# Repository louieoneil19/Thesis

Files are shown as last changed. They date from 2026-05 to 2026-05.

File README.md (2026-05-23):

# Solar-Powered Buck-Boost Converter — Thesis Project

An STM32-based MPPT buck-boost converter for solar-powered soil moisture monitoring and pump control.

## Overview

This project presents the design and implementation of a solar-powered irrigation system optimised for off-grid rural use. The system integrates a photovoltaic panel, a non-inverting DC–DC buck-boost converter, a backup battery, a water pump, and a microcontroller-based control unit on a custom four-layer printed circuit board. A perturb-and-observe maximum power point tracking (MPPT) algorithm is implemented to maximise energy extraction from the solar panel across varying irradiance and temperature conditions. A capacitive soil moisture sensor drives a separate pump-control loop, varying pump speed in discrete stages based on measured soil dryness. The converter was validated in MATLAB Simulink and characterised experimentally through duty-cycle sweeps, with the measured input–output relationships closely matching theoretical predictions. The completed system demonstrates autonomous solar energy harvesting and adaptive water delivery, providing a viable platform for off-grid agricultural applications in resource-limited regions.

## Repository Structure
```
.
├── firmware/          STM32CubeIDE project (STM32F446RE)
│   ├── Core/          Application source code (main.c, peripherals)
│   ├── Drivers/       STM32 HAL drivers
│   └── *.ioc          STM32CubeMX configuration
│
└── hardware/          KiCad PCB design
├── SolarSystem/   KiCad project files (schematic + PCB layout)
├── gerbers/       Manufacturing files for PCB fabrication
├── libraries/     Custom footprints and symbols
├── SolarSystem Layout.pdf   PDF file of SolarSystem schematics
└── SolarSystem_BOM.csv   Bill of materials
```

## Where to Find the Main Code

The primary application logic lives in:

**[`firmware/Core/Src/main.c`](firmware/Core/Src/main.c)**

This file contains all the custom application code, including:

- **MPPT algorithm** — `Run_MPPT()`, `track_mpp_20_seconds()`
- **I-V curve sweep** — `Run_IV_Sweep()`
- **Sensor reading** — `Read_Panel_Sensors()`, `Process_ADC_Buffer()`
- **Soil moisture control** — `Run_Soil_Moisture_Control()`, `find_moisture_calibration()`
- **Pump control** — `Set_Converter_Duty()`, `Set_Manual_Duties()`
- **Calibration routines** — `find_calibration_values()`
- **Telemetry output** — `Print_Panel_Sensors()`

The other files in `firmware/Core/Src/` (such as `stm32f4xx_hal_msp.c`, `stm32f4xx_it.c`, `syscalls.c`, `sysmem.c`, and `system_stm32f4xx.c`) are auto-generated by STM32CubeMX and contain HAL initialisation and system-level boilerplate — they generally don't need to be modified.

## Hardware

- **MCU:** STM32F446RE (ARM Cortex-M4 @ 180 MHz)
- **Topology:** Synchronous buck-boost converter
- **Sensing:** Panel voltage/current (ADC), soil moisture probe
- **Control:** PWM duty-cycle modulation for MPPT
- **Output:** Pump driver with variable speed (PUMP_OFF/SLOW/FAST/FULL)

## Firmware Features

- MPPT algorithm (perturb and observe)
- I-V curve sweep for panel characterisation
- Soil moisture calibration (dry/wet bounds)
- Automated pump control based on moisture thresholds
- UART telemetry for monitoring and debugging

## Building the Firmware

**Requirements:**
- [STM32CubeIDE](https://www.st.com/en/development-tools/stm32cubeide.html) (tested on v1.x)
- ST-LINK programmer (or compatible STM32 board with built-in debugger)

**Steps:**
1. Open STM32CubeIDE
2. **File → Import → Existing Projects into Workspace**
3. Browse to the `firmware/` folder in this repository
4. Select the project and click **Finish**
5. Build with **Cmd+B** (macOS) or **Ctrl+B** (Windows/Linux)
6. Flash to the target with the green Run arrow

## Viewing the Hardware

The PCB design is created in [KiCad](https://www.kicad.org/) (free, open-source).

**To view the schematic and PCB layout:**
1. Install KiCad (version 7 or newer)
2. Open `hardware/SolarSystem/` and double-click the `.kicad_pro` file

**Manufacturing files:**
The `hardware/gerbers/` folder contains ready-to-fabricate Gerber files compatible with most PCB manufacturers (JLCPCB, PCBWay, OshPark, etc.).

## Author

Louie O'Neil

## License

This project is shared as part of academic thesis work. See `LICENSE` for details.

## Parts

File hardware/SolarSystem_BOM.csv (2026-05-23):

Reference | Qty | DigiKey_Part_Number | Manufacturer_Part_Number | Purchase-URL | Description
U9 | 1 | 296-41360-1-ND | OPA237UA/2K5 | https://www.digikey.com.au/en/products/detail/texas-instruments/OPA237UA-2K5/301208 | Standard (General Purpose) Amplifier 1 Circuit 8-SOIC
U4,U6,U8 | 3 | TC4420CPA-ND | TC4420CPA | https://www.digikey.com.au/en/products/detail/microchip-technology/TC4420CPA/267369 | Low-Side Gate Driver IC Non-Inverting 8-PDIP
U3,U5,U7 | 3 | 516-1741-5-ND | HCPL-2211-300E | https://www.digikey.com.au/en/products/detail/broadcom-limited/HCPL-2211-300E/1236284 | Logic Output Optoisolator 5MBd Push-Pull, Totem Pole 3750Vrms 1 Channel 5kV/µs, 10kV/µs CMTI 8-DIP Gull Wing
U2 | 1 | 620-1634-1-ND | ACS722LLCTR-05AB-T | https://www.digikey.com/en/products/detail/allegro-microsystems/ACS722LLCTR-05AB-T/4915375 | ±5A Bidirectional Hall-Effect Current Sensor, +3.3V supply, 264mV/A, SOIC-8
Rd4,Rd8,Rd12 | 3 | 118-CR0805-JW-220ELFCT-ND | CR0805-JW-220ELF | https://www.digikey.com/en/products/detail/bourns-inc/CR0805-JW-220ELF/3785269 | 22 Ohms ±5% 0.125W, 1/8W Chip Resistor 0805 (2012 Metric) Moisture Resistant Thick Film
Rd3,Rd7,Rd11 | 3 | RG20P5.60KBCT-ND | RG2012P-562-B-T5 | https://www.digikey.com/en/products/detail/susumu/RG2012P-562-B-T5/1266880 | 5.6 kOhms ±0.1% 0.125W, 1/8W Chip Resistor 0805 (2012 Metric) Anti-Sulfur, Automotive AEC-Q200 Thin Film
Rd2,Rd6,Rd10 | 3 | 311-10.0CRCT-ND | RC0805FR-0710RL | https://www.digikey.com/en/products/detail/yageo/RC0805FR-0710RL/727534 | 10 Ohms ±1% 0.125W, 1/8W Chip Resistor 0805 (2012 Metric) Moisture Resistant Thick Film
Rd1,Rd5,Rd9 | 3 | 2019-RN73H2ATTD2200F100CT-ND | RN73H2ATTD2200F100 | https://www.digikey.com/en/products/detail/koa-speer-electronics-inc/RN73H2ATTD2200F100/10089545 | 220 Ohms ±1% 0.125W, 1/8W Chip Resistor 0805 (2012 Metric) Automotive AEC-Q200, Moisture Resistant Metal Film
R2,R3,R4,R5,R6 | 5 | 2019-RN73H2ATTD1002B25CT-ND | RN73H2ATTD1002B25 | https://www.digikey.com/en/products/detail/koa-speer-electronics-inc/RN73H2ATTD1002B25/10060593 | 10 kOhms ±0.1% 0.125W, 1/8W Chip Resistor 0805 (2012 Metric) Automotive AEC-Q200, Moisture Resistant Metal Film
R1 | 1 | 541-1891-1-ND | TNPW080598K8BEEN | https://www.digikey.com/en/products/detail/vishay-dale/TNPW080598K8BEEN/4271755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 | 98.8 kOhms ±0.1% 0.26W Chip Resistor 0805 (2012 Metric) Anti-Sulfur, Automotive AEC-Q200, Moisture Resistant Thin Film
M1,M2,M3 | 3 | IRLZ44NSTRLPBFCT-ND | IRLZ44NSTRLPBF | https://www.digikey.com/en/products/detail/infineon-technologies/IRLZ44NSTRLPBF/856858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 | N-Channel 55 V 47A (Tc) 3.8W (Ta), 110W (Tc) Surface Mount D2PAK
L2 | 1 | 118-SRR1210-471MCT-ND | SRR1210-471M | https://www.digikey.com/en/products/detail/bourns-inc/SRR1210-471M/2352900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 | 470 µH Shielded Drum Core, Wirewound Inductor 1.2 A 820mOhm Max Nonstandard
L1 | 1 | 732-11720-ND | 74437529203681 | https://www.digikey.com/en/products/detail/w%C3%BCrth-elektronik/74437529203681/8134294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 | 680 µH Shielded Drum Core, Wirewound Inductor 4.8 A 118.3mOhm Nonstandard
J_BAT+1,J_M1+1,J_M2+1,J_M3+1,J_Pump+1,J_PV+1,J_VDD1+1 | 7 | CT3151V1-0-ND | CT3151V1-0 | https://www.digikey.com/en/products/detail/cal-test-electronics/CT3151V1-0/7383486 | SAFETY JACK 4MM HOR PCB BLK
J_BAT-1,J_M1-1,J_M2-1,J_M3-1,J_Pump-1,J_PV-1,J_VDD1-1 | 7 | CT3151V1-2-ND | CT3151V1-2 | https://www.digikey.com/en/products/detail/cal-test-electronics/ct3151v1-2/7383485 | SAFETY JACK 4MM HOR PCB RED
D6,D8,D10 | 3 | MM5Z15VT1GOSCT-ND | MM5Z15VT1G | https://www.digikey.com/en/products/detail/onsemi/MM5Z15VT1G/921077 | Zener Diode 15 V 500 mW ±5% Surface Mount SOD-523
D5,D7,D9 | 3 | 1N4148FS-ND | 1N4148 | https://www.digikey.com/en/products/detail/onsemi/1N4148/458603?s=N4IgTCBcDaIIwDkAsckA4BiBlAtAgIiALoC%2BQA | 100V 0.15A standard switching diode, DO-35
D1,D2,D3,D4 | 4 | 4878-SK34SMA-3GCT-ND | SK34SMA-3G | https://www.digikey.com/en/products/detail/diotec-semiconductor/SK34SMA-3G/13155211 | Schottky Diodes & Rectifiers Schottky Diode, SMA, 40V, 3A
Cvs1,Cvs4,Cvs5 | 3 | 490-6113-1-ND | GRM0335C1H101JA01D | https://www.digikey.com/en/products/detail/murata-electronics/grm0335c1h101ja01d/2269165 | Murata 0201 GRM 100pF Ceramic Multilayer Capacitor, 50 V, +125C, C0G Dielectric, +/-5% SMD
CL1,C_opamp1 | 2 | 490-1313-1-ND | GRM155R71C103KA01D | https://www.digikey.com/en/products/detail/murata-electronics/grm155r71c103ka01d/587215 | 10000 pF ±10% 16V Ceramic Capacitor X7R 0402 (1005 Metric)
Cd1,Cd3,Cpv1,Cpv2,Cpv3 | 5 | 2679-AGC1210X7R500-106KNE-CT-ND | AGC1210X7R500-106KNE | https://www.digikey.com/en/products/detail/venkel/AGC1210X7R500-106KNE-CT/21343605 | Auto Grade Capacitor,1210,X7R,50V,10uF,+/-10%
Cb2,Cb3 | 2 | 2679-AGC0603X7R250-105KXP-CT-ND | AGC0603X7R250-105KXP-CT | https://www.digikey.com/en/products/detail/venkel/AGC0603X7R250-105KXP-CT/21344657 | 1 F +/-10% 25V Ceramic Capacitor X7R 0603 (1608 Metric)
Cb1,Cb4,Cb5,Cb6,Cd2,Cd4,Cvs2,Cvs3 | 8 | 490-10430-1-ND | GRM033R6YA104KE14D | https://www.digikey.com/en/products/detail/murata-electronics/GRM033R6YA104KE14D/5027515 | Multilayer Ceramic Capacitors MLCC - SMD/SMT 0201 0.10uF 35volts *Derate Voltage/Temp
C2 | 1 | 732-8501-1-ND | 865080540002 | https://www.digikey.com/en/products/detail/w%C3%BCrth-elektronik/865080540002/5728096 | CAP ALUM 4.7UF 20% 35V SMD
C1 | 1 | 1572-ATB107M035CT-ND | ATB107M035 | https://www.digikey.com/en/products/detail/cornell-dubilier-knowles/ATB107M035/7393935 | Aluminum Electrolytic Capacitors - SMD 35VDC 100uF 20% 420mA a. 120Hz

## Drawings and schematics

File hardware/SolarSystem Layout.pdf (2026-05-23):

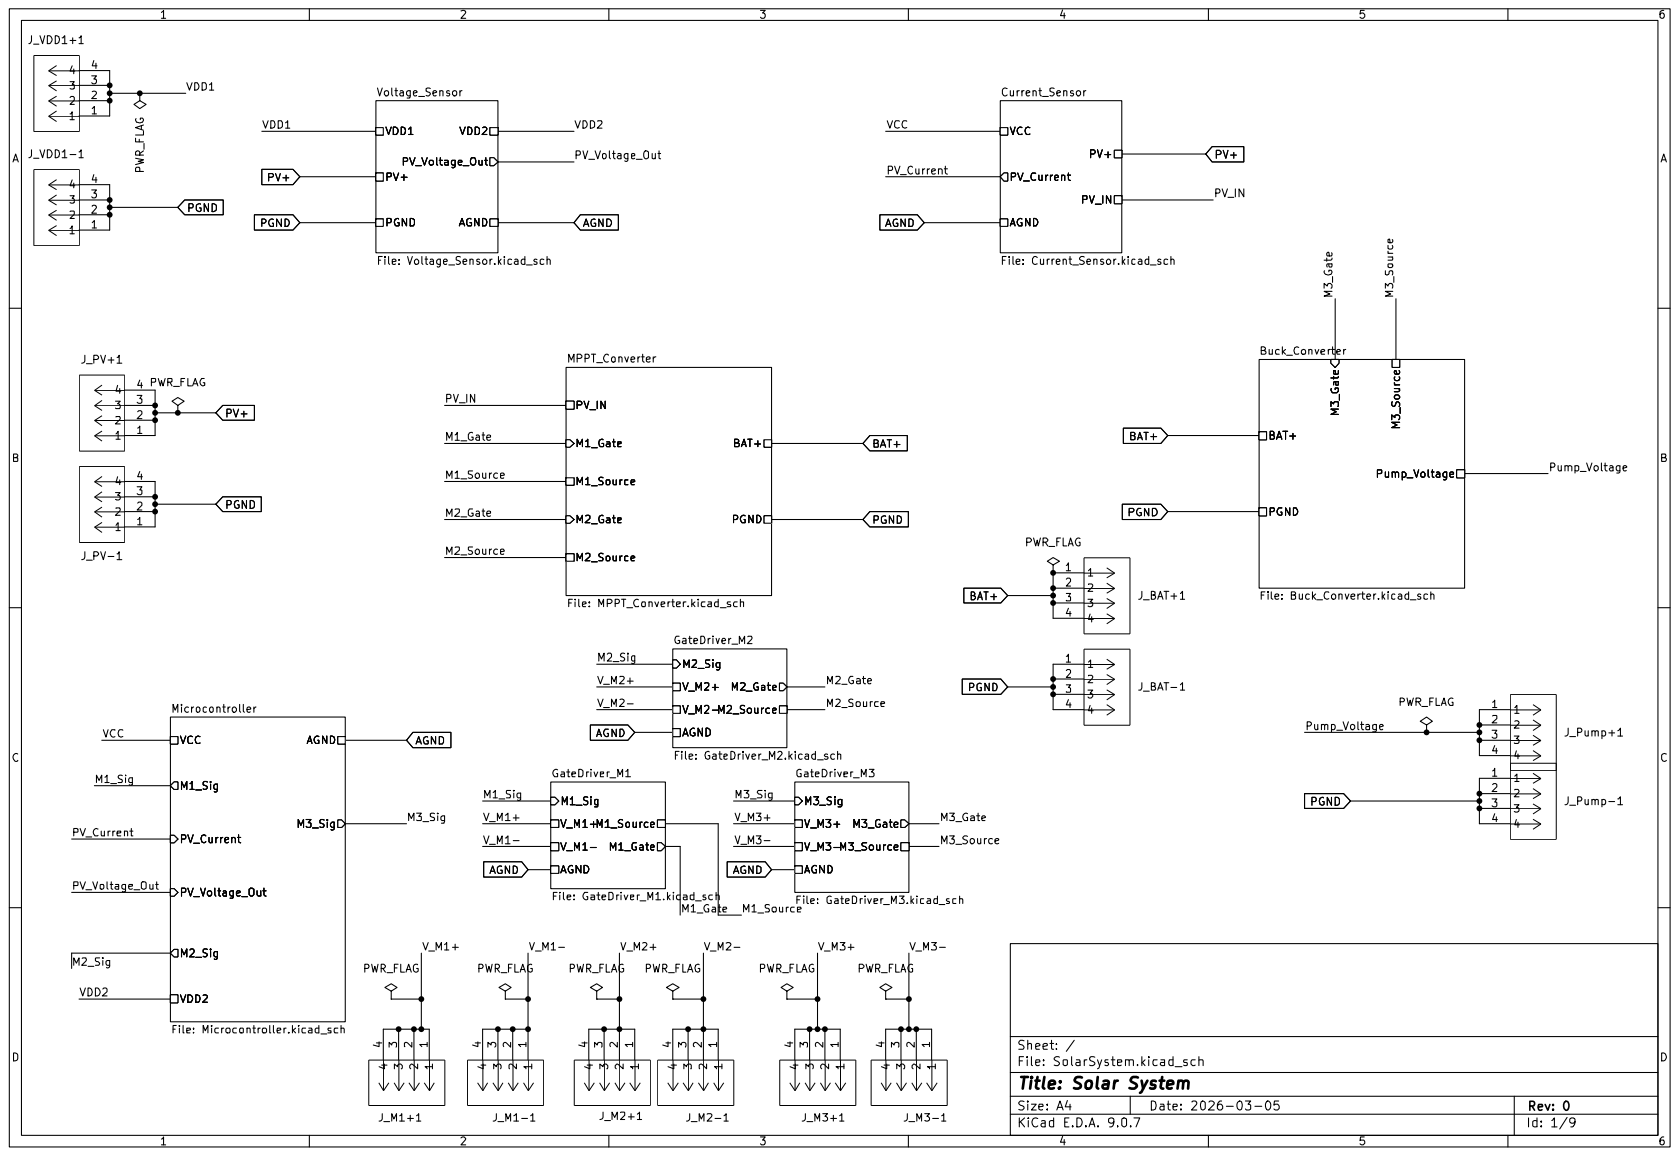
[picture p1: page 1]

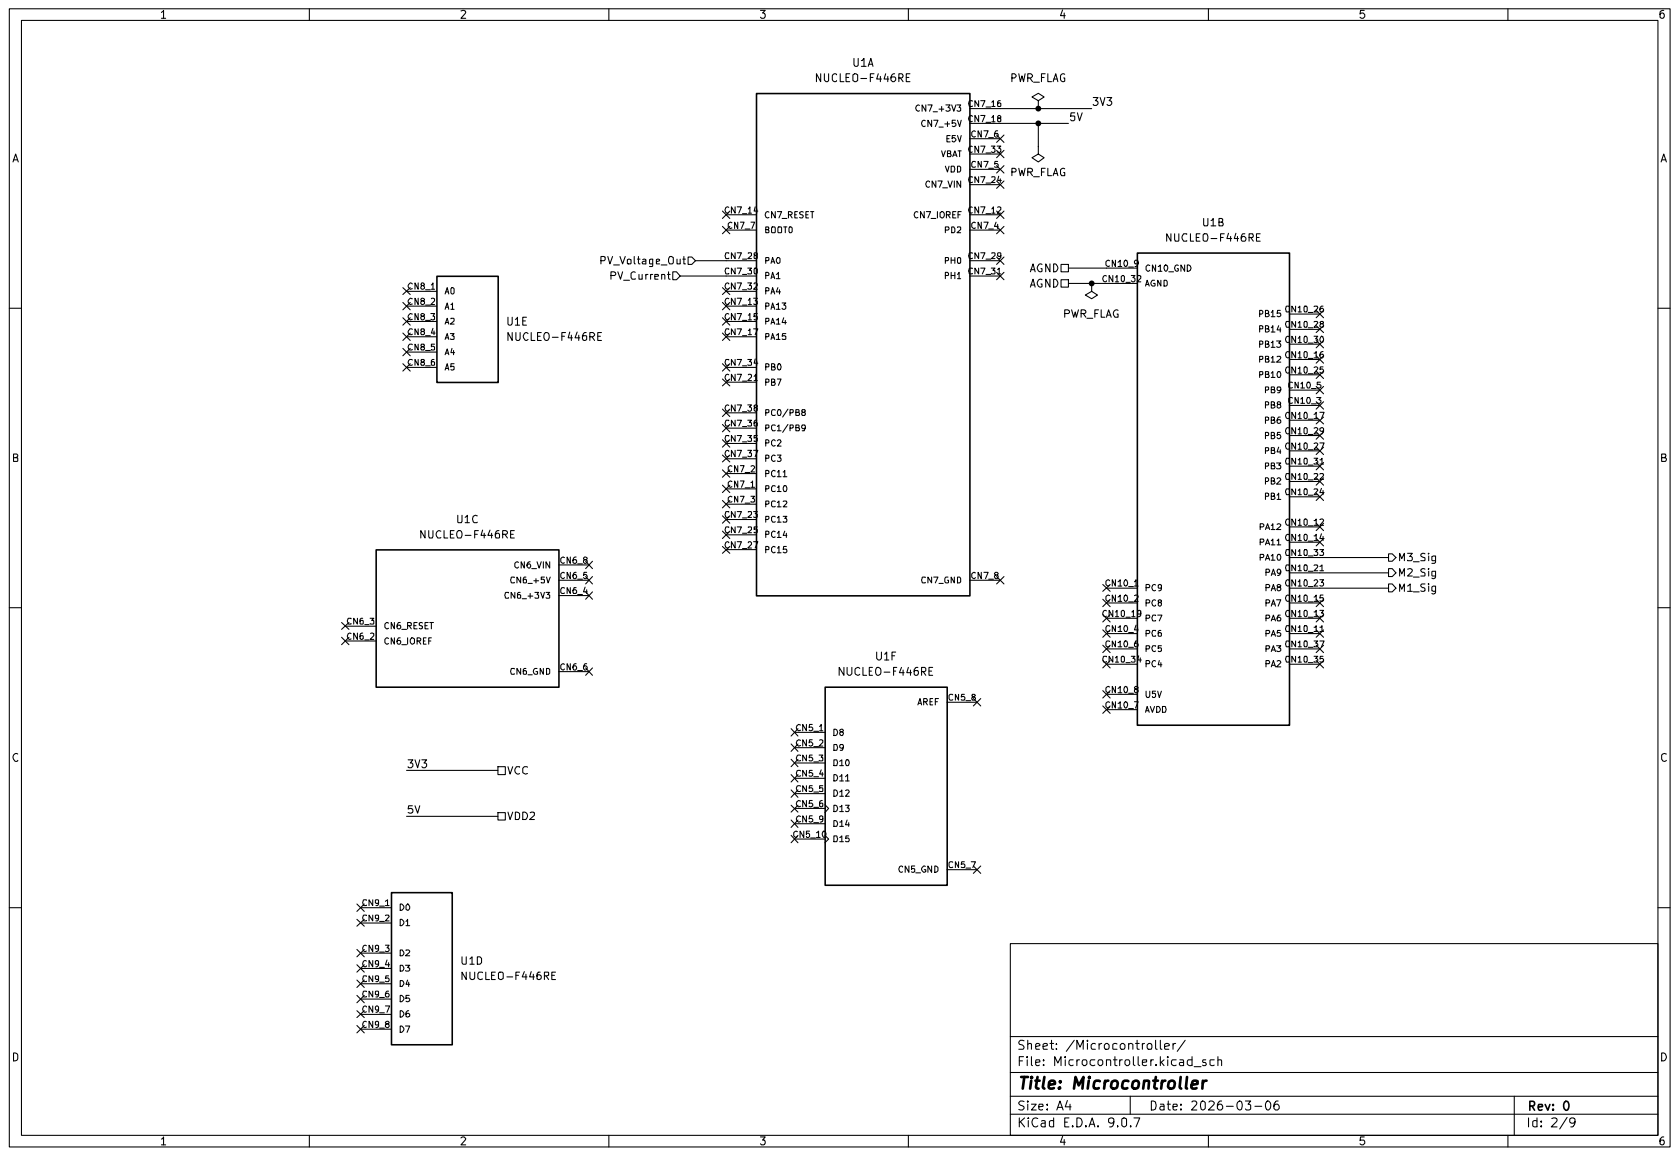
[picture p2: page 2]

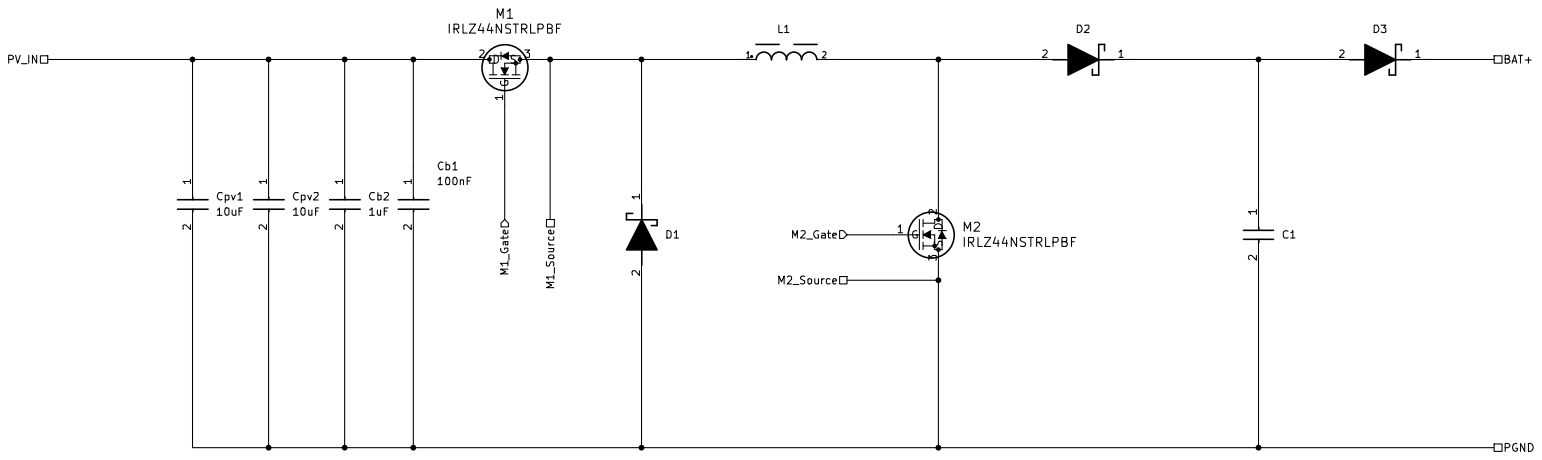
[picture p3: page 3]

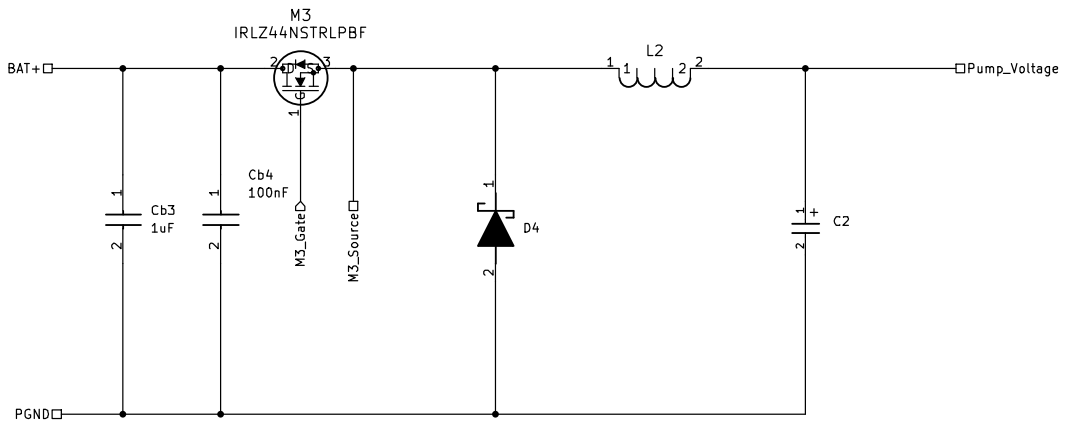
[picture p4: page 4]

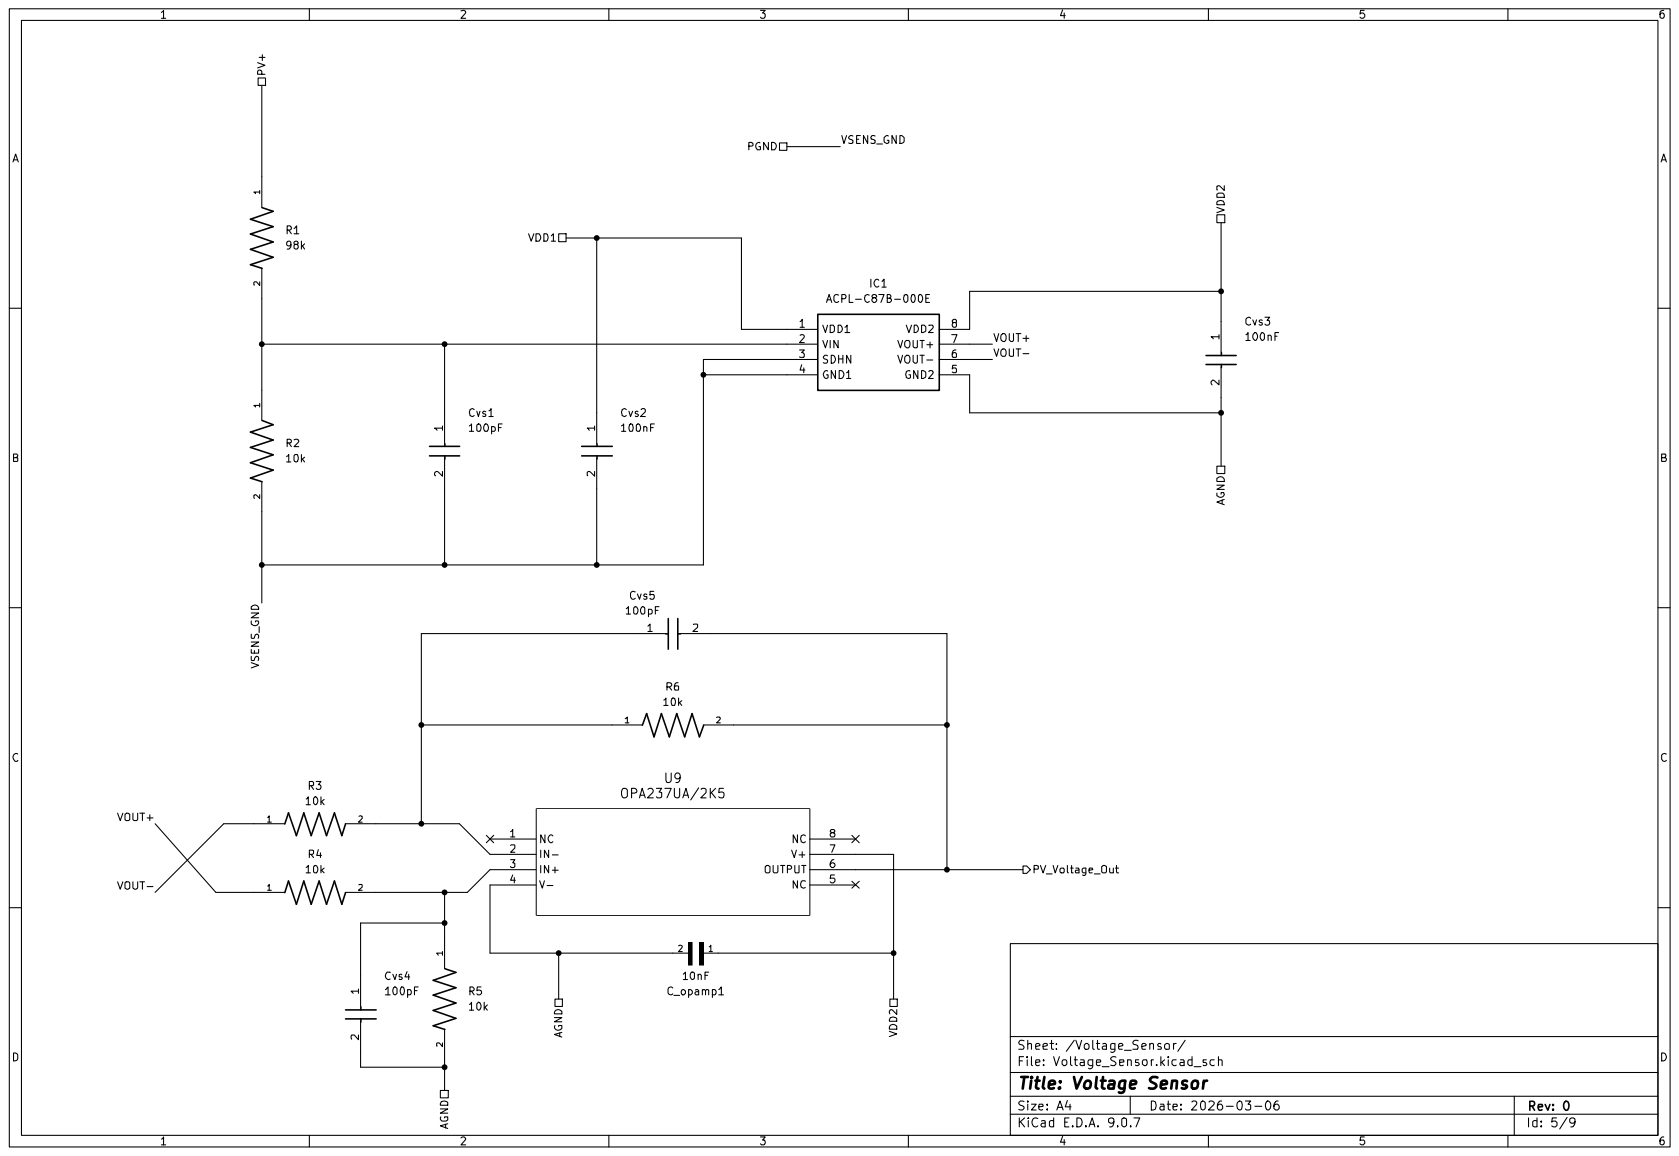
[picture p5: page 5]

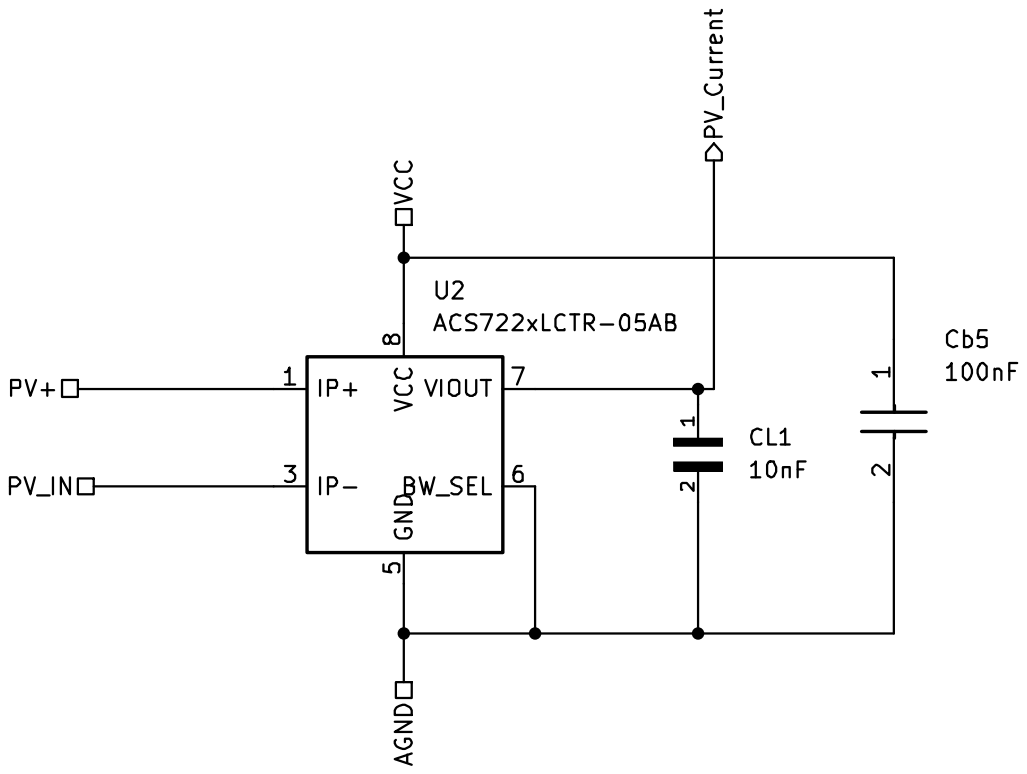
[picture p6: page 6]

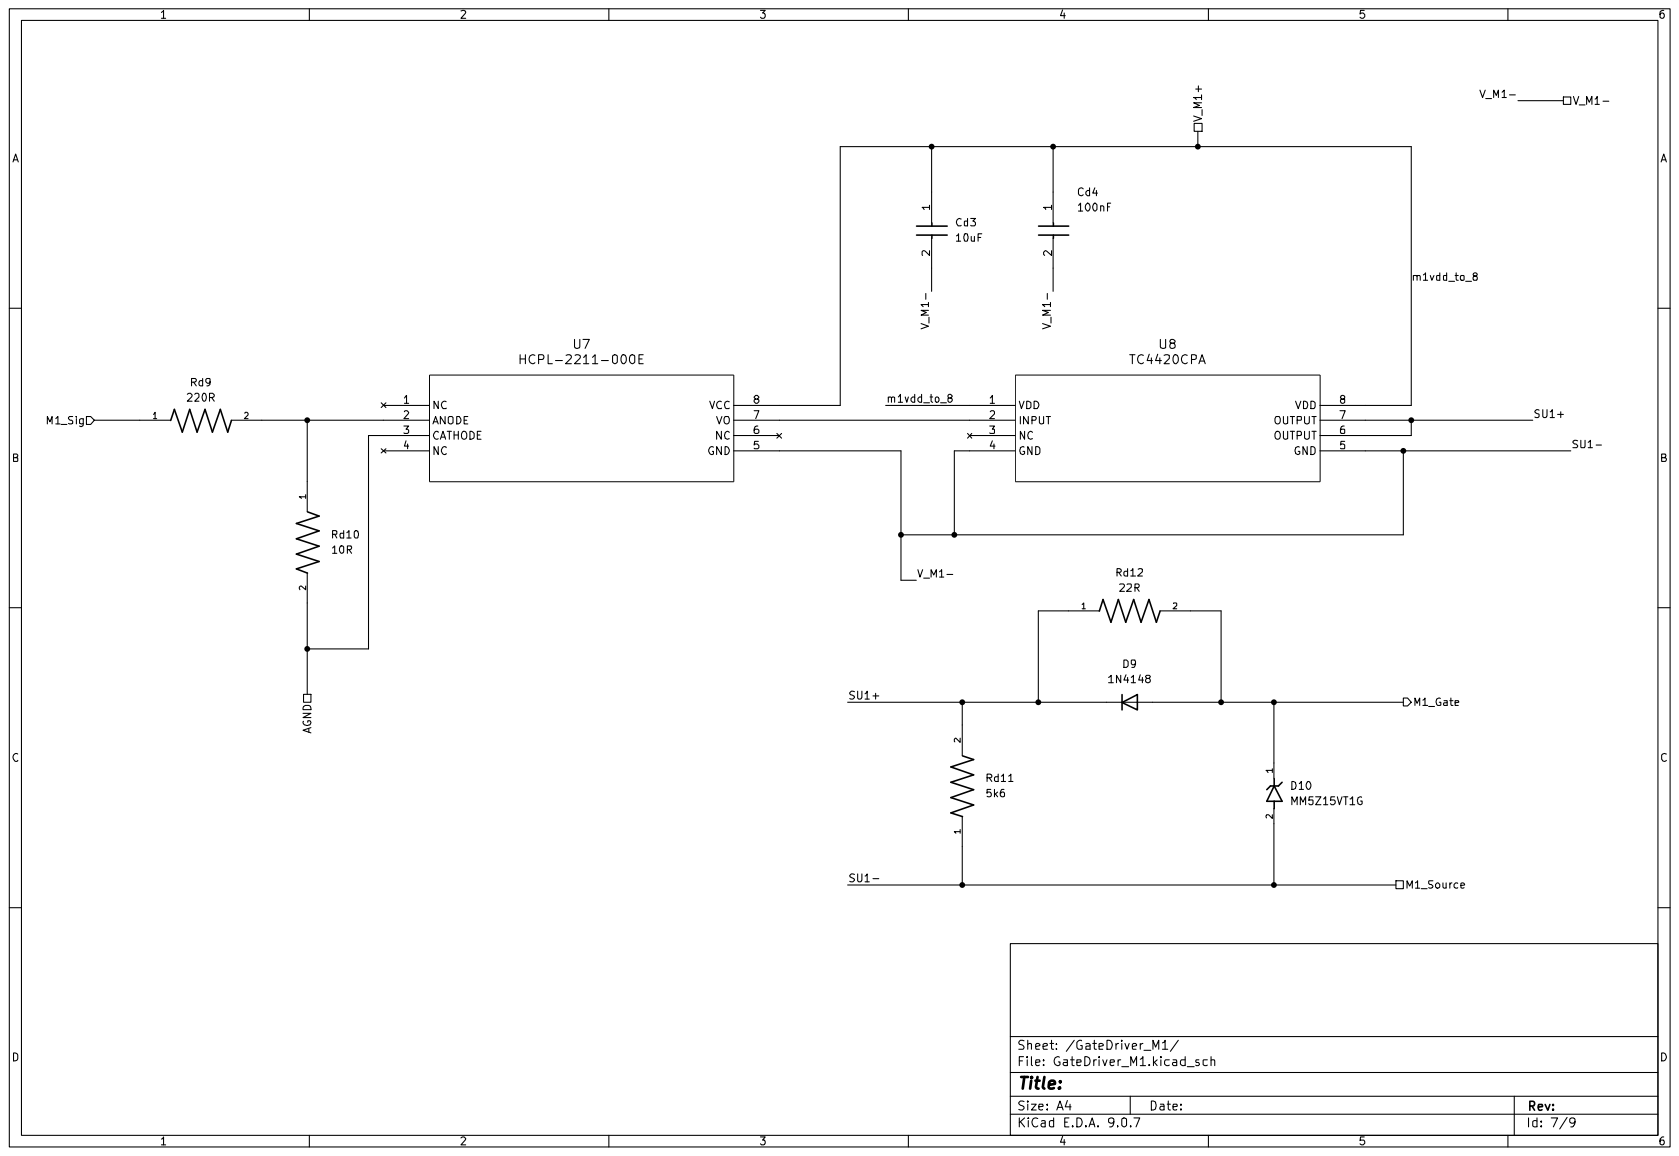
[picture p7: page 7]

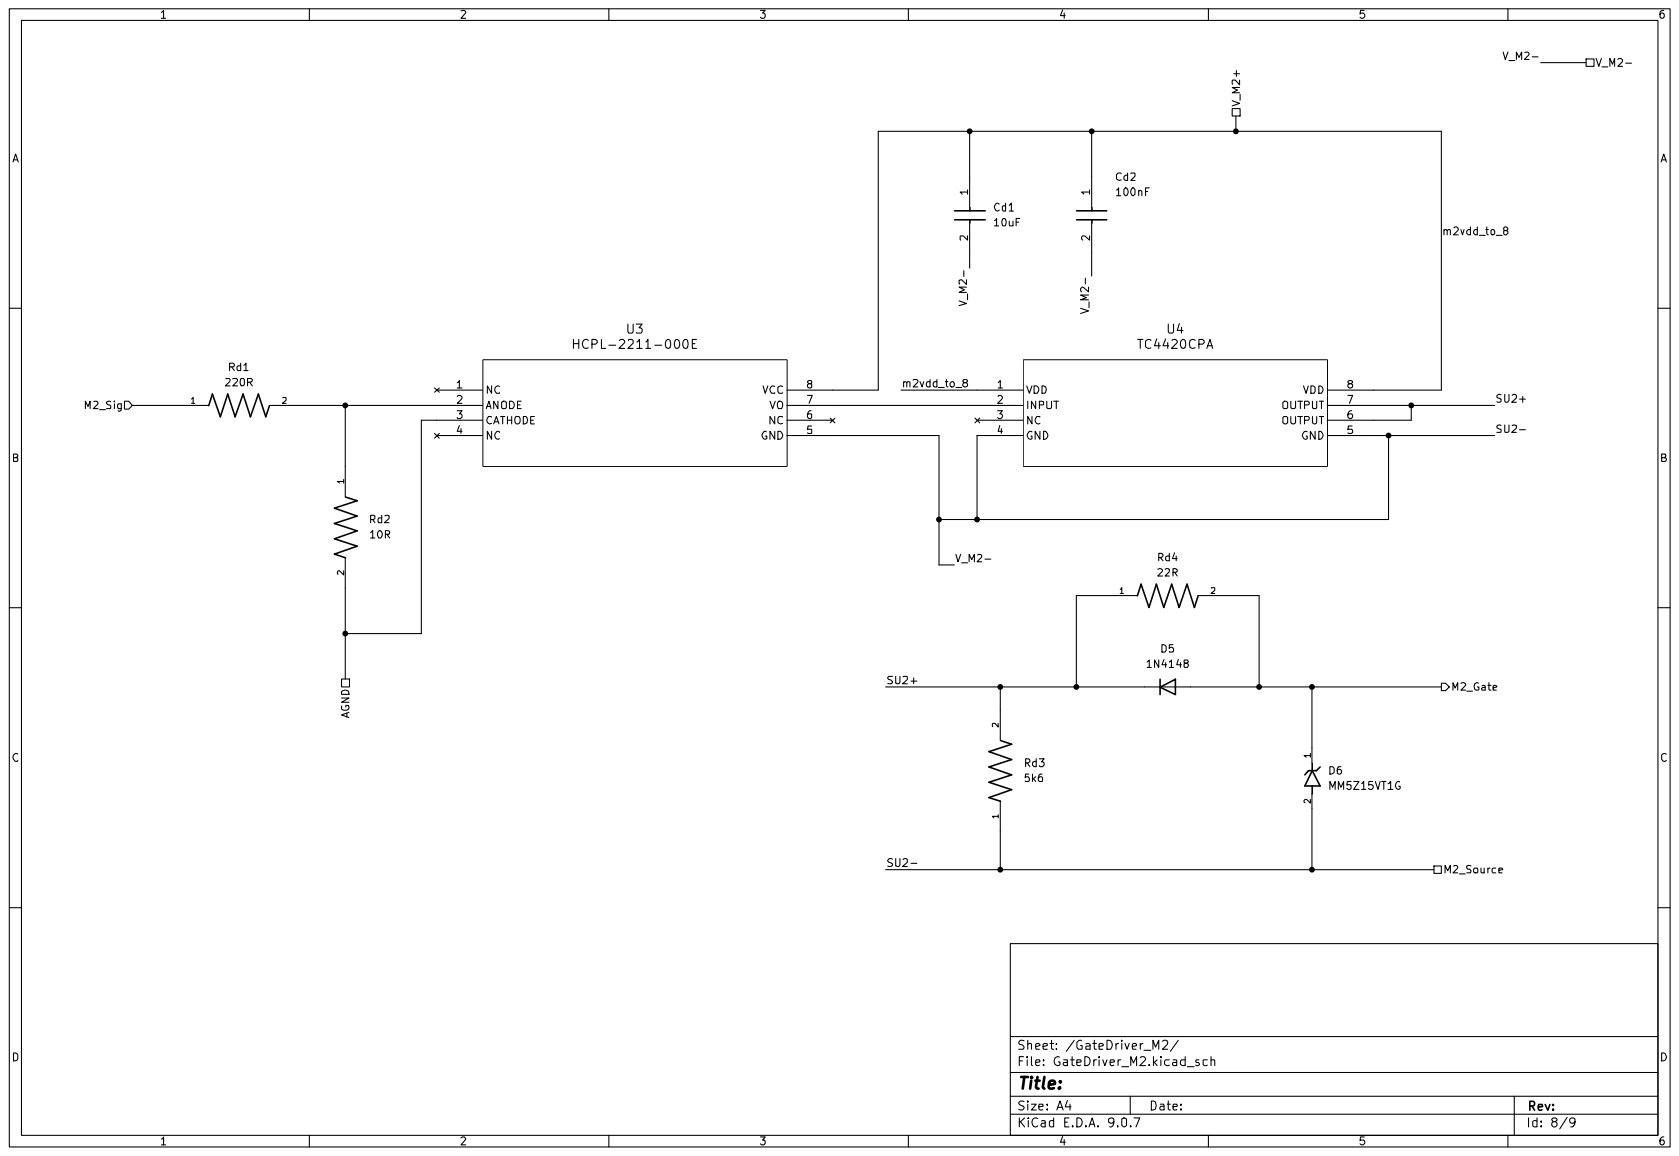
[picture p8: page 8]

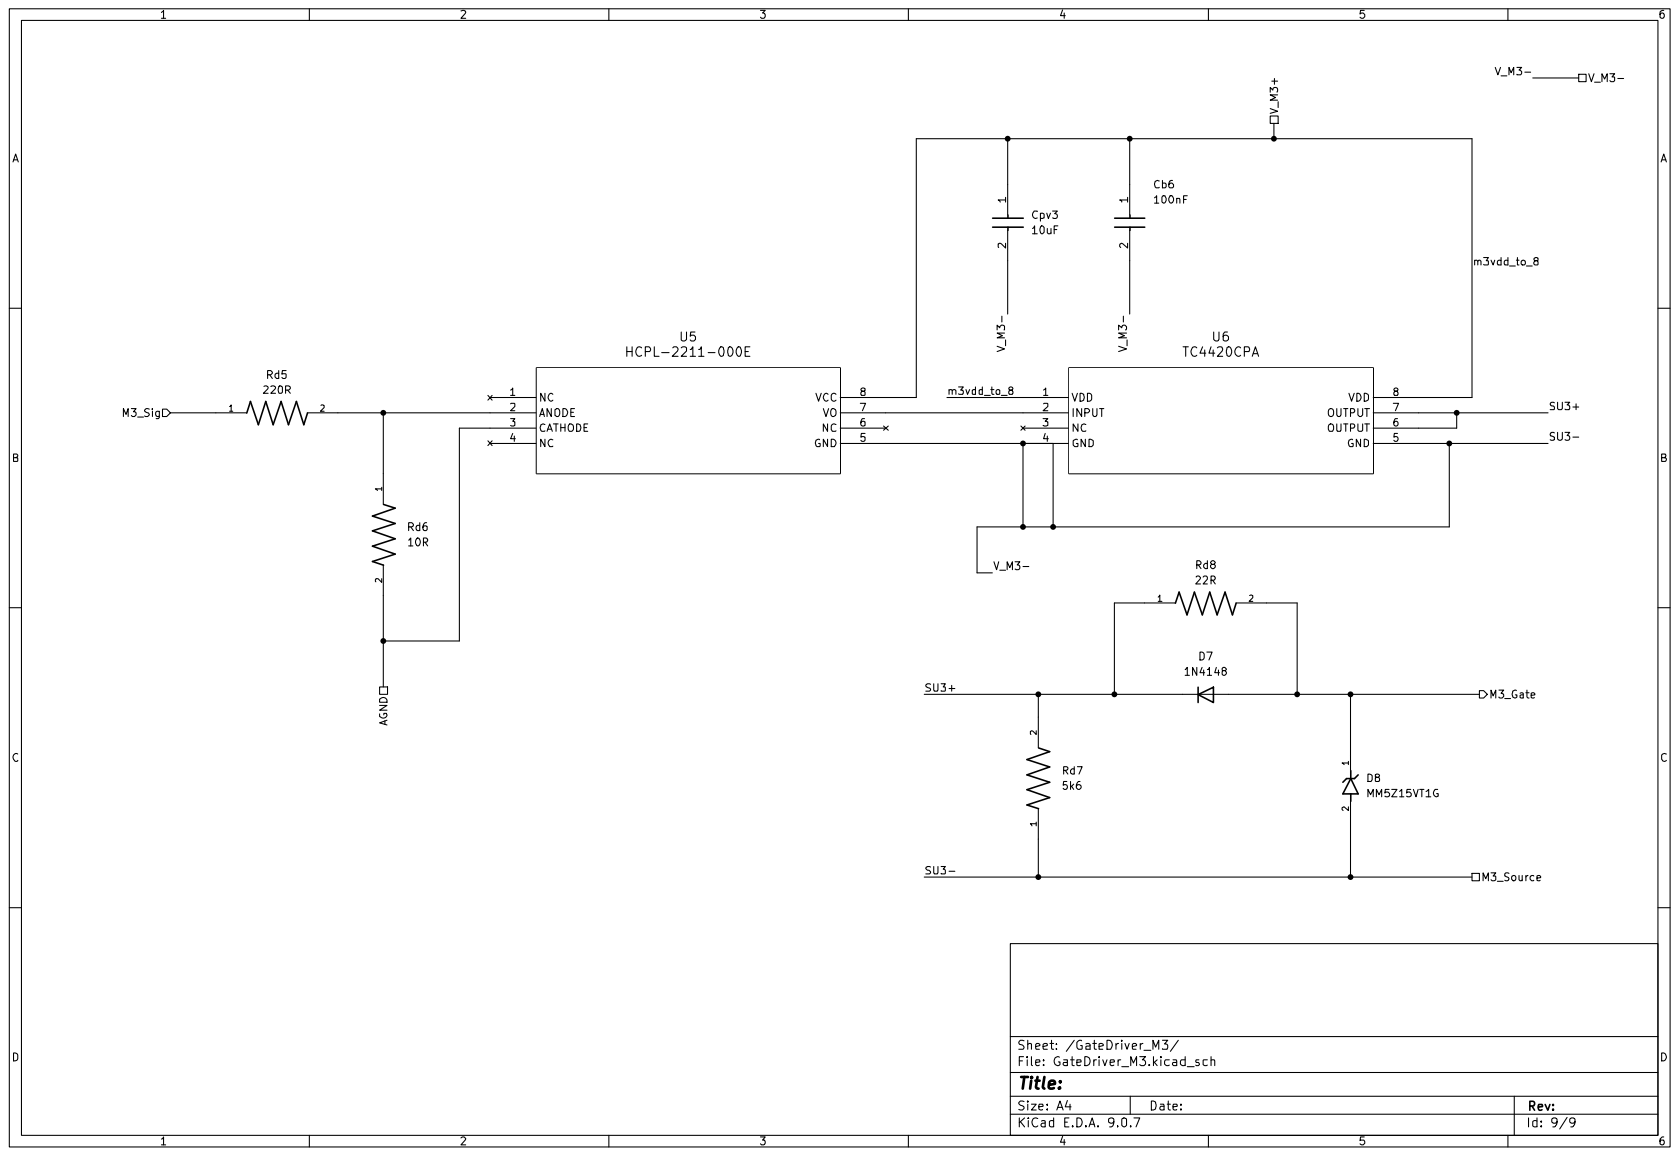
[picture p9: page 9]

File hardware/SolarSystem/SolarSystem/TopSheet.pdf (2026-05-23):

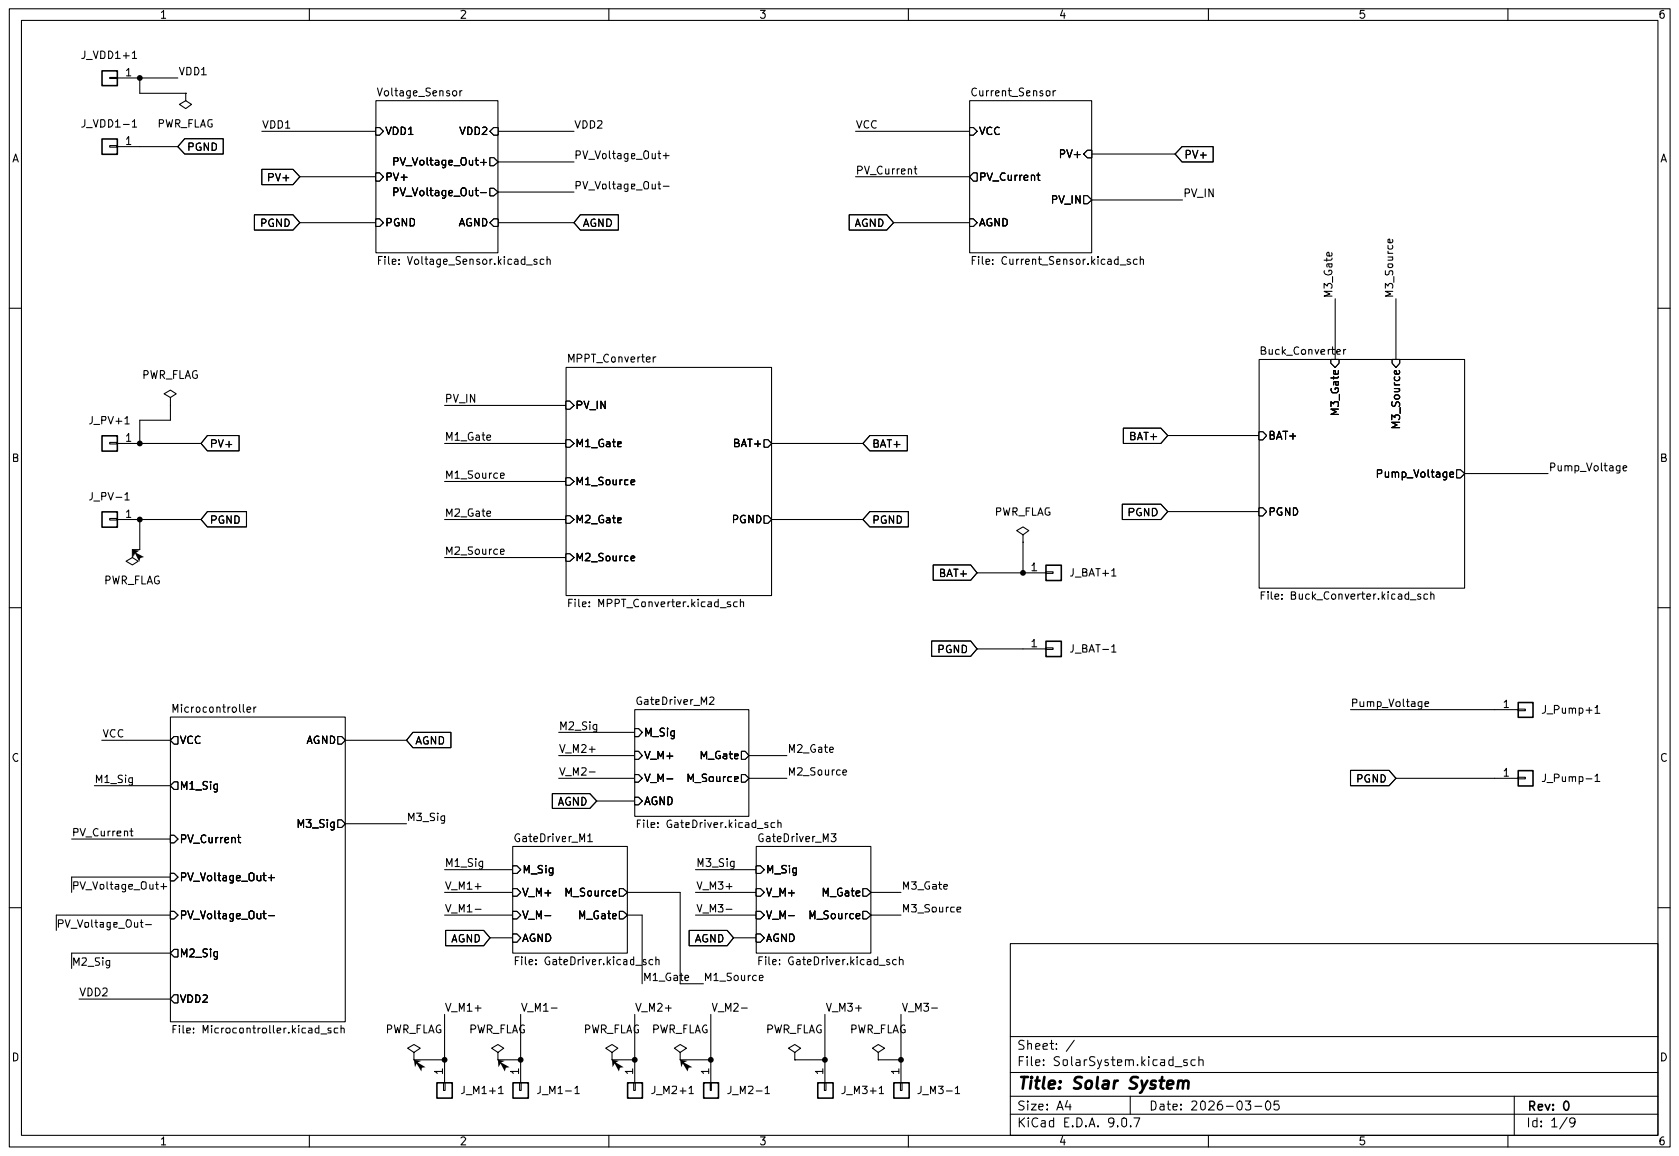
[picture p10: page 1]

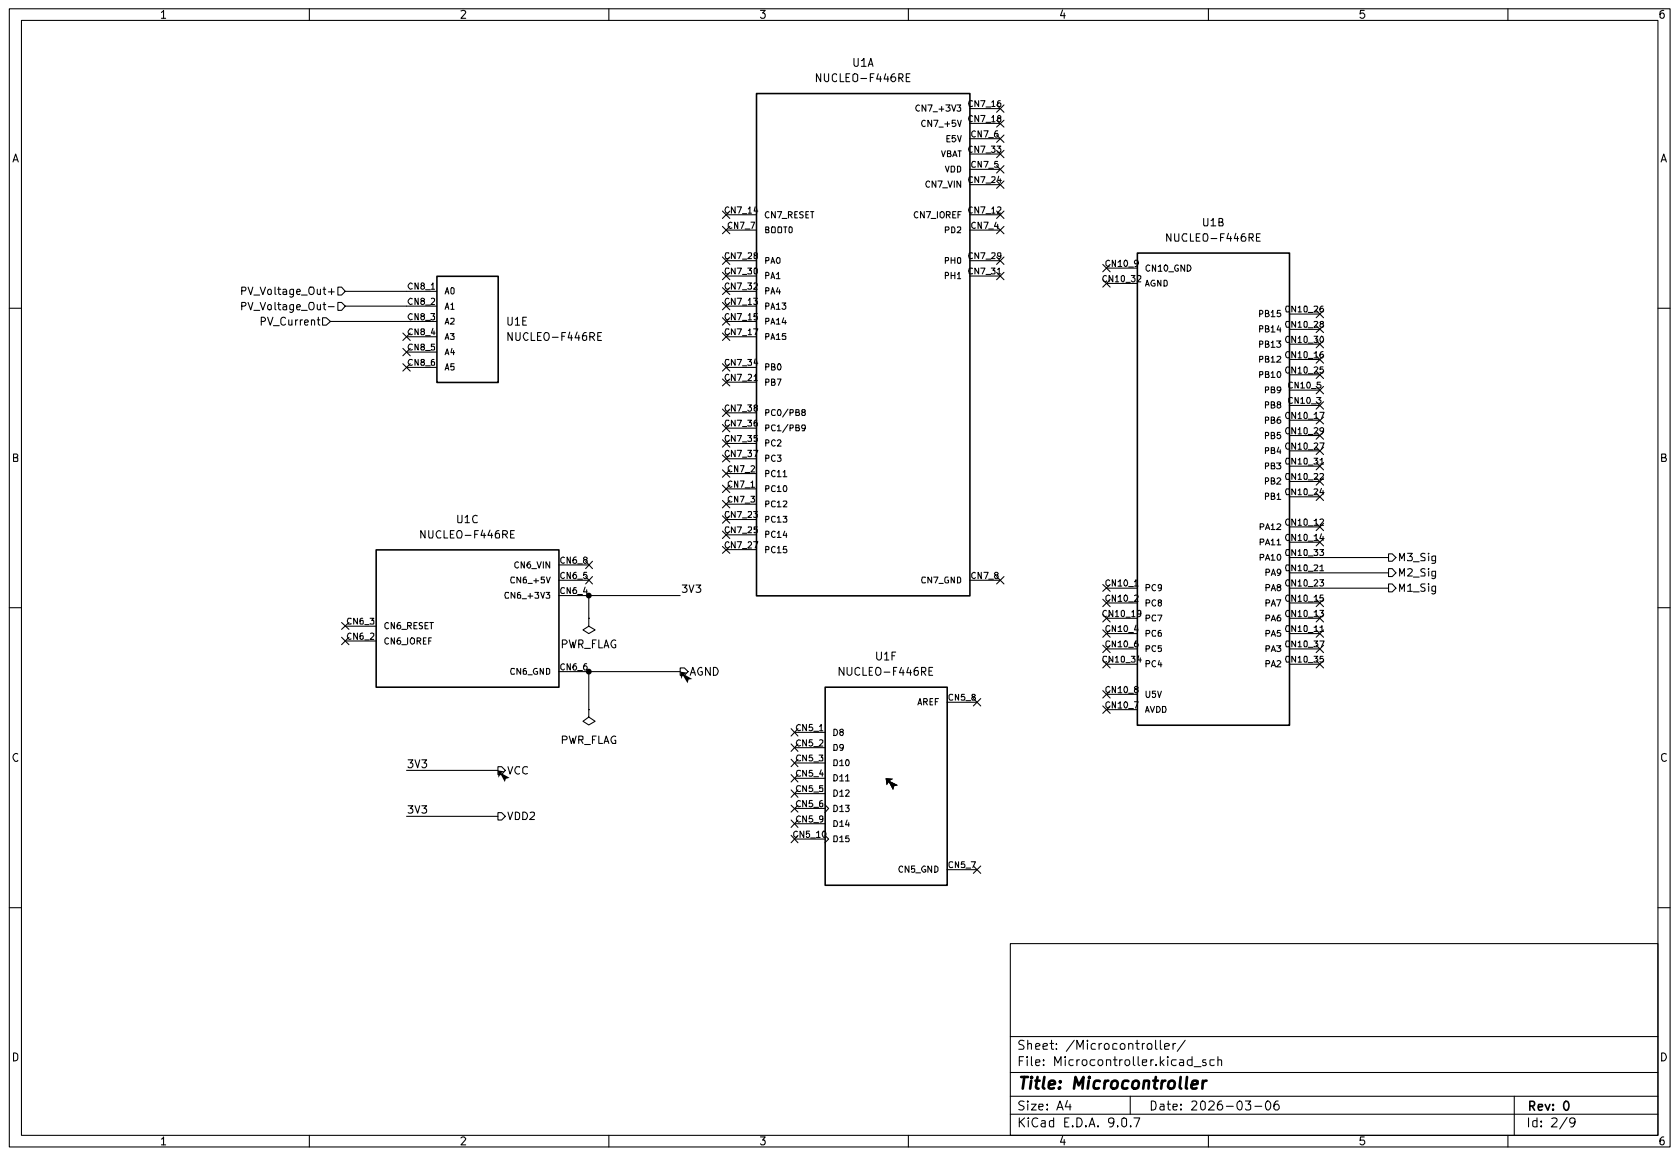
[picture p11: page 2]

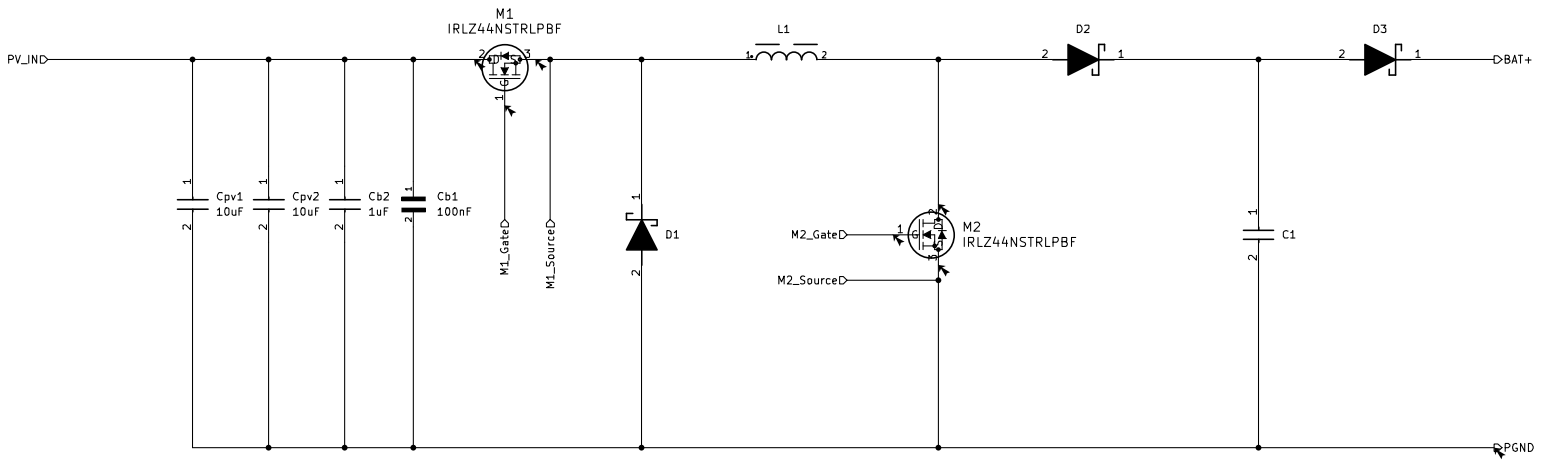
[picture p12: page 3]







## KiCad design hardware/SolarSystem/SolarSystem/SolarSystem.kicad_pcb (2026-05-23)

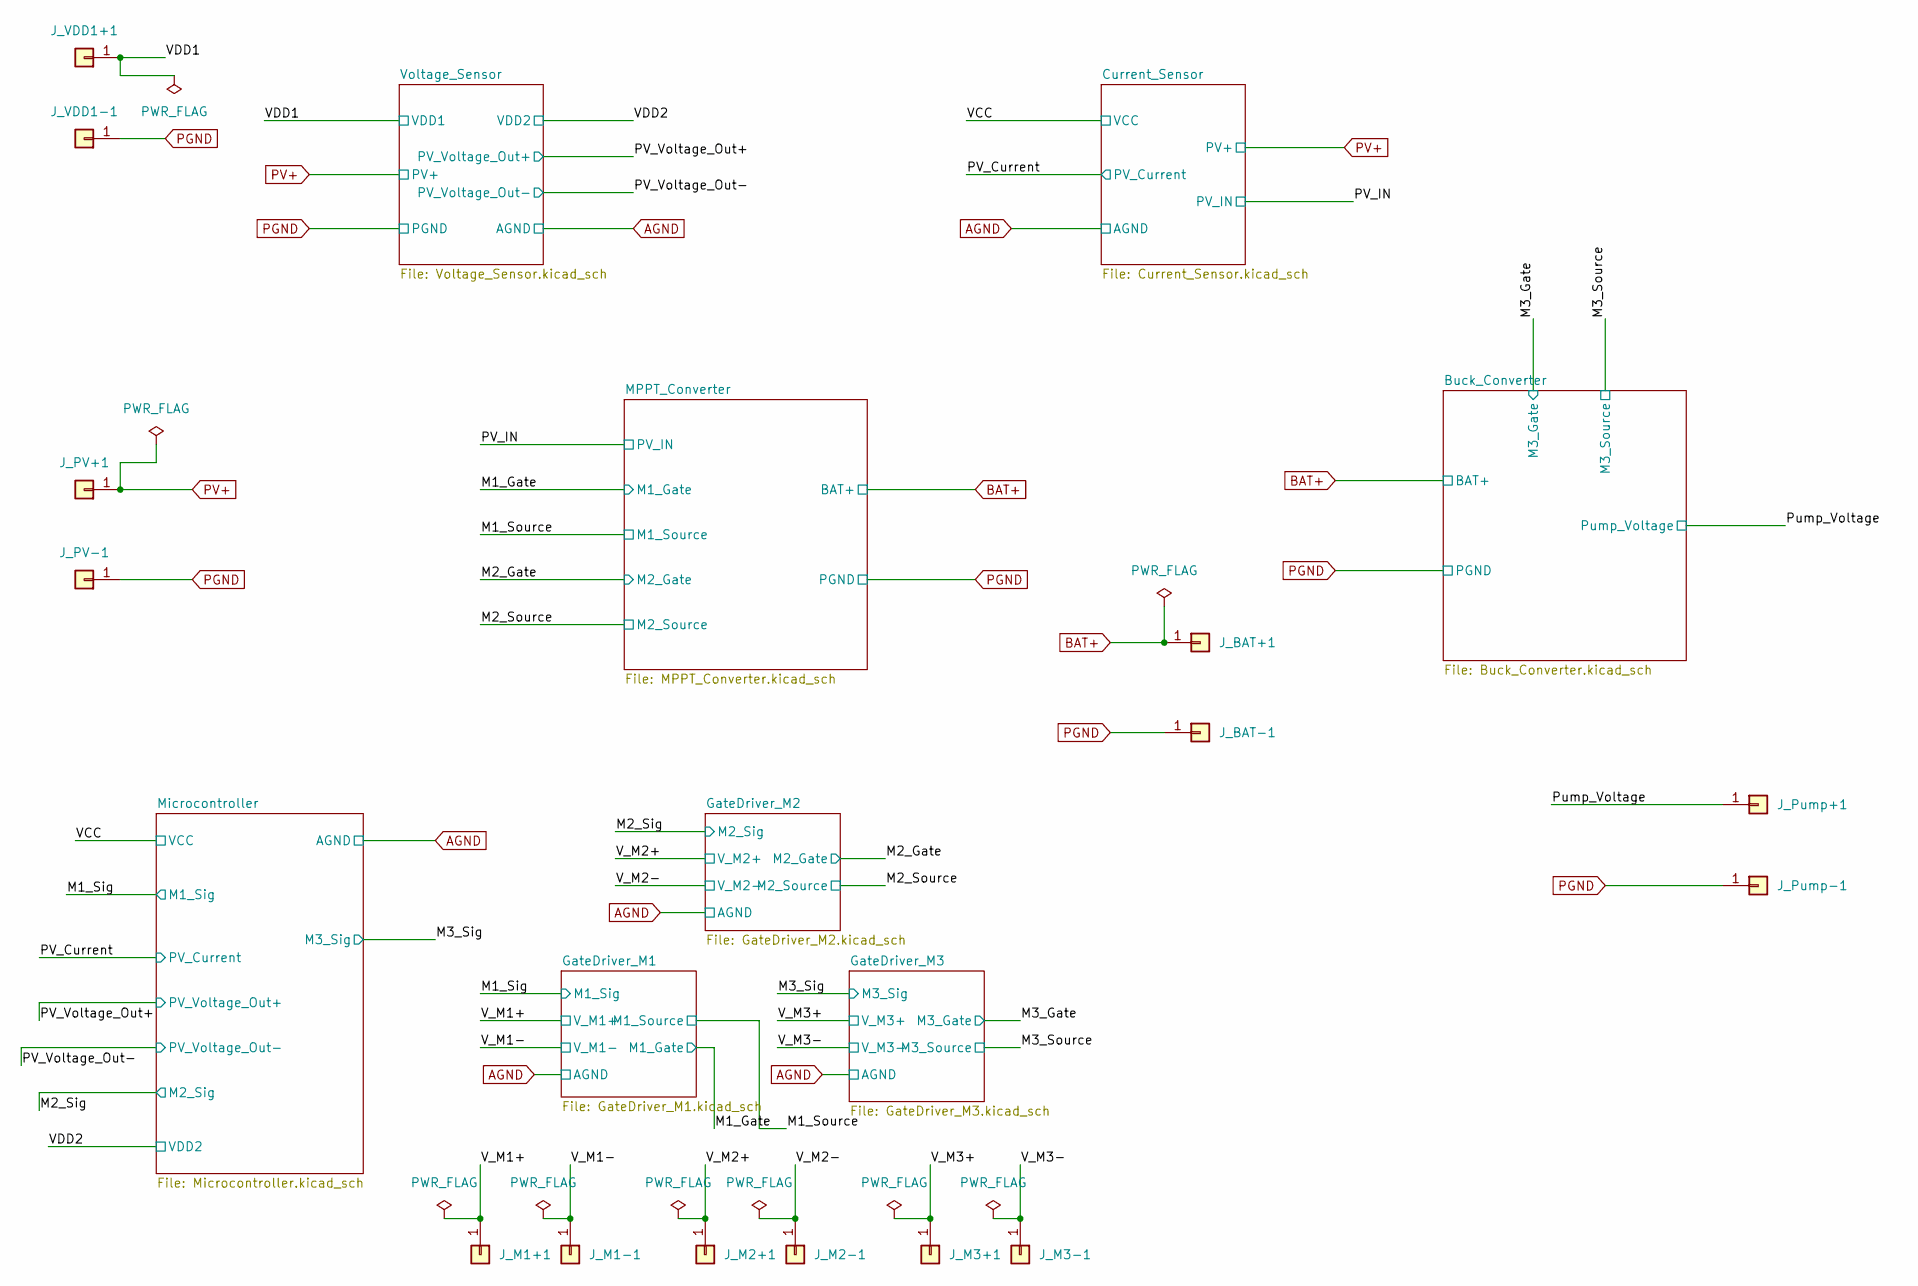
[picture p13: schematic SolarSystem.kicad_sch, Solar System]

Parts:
J_BAT+1: Conn_01x01; Banana_Jack_1Pin
J_BAT-1: Conn_01x01; Banana_Jack_1Pin
J_M1+1, J_M1-1, J_M2+1, J_M2-1, J_M3+1, J_M3-1: Conn_01x01; Banana_Jack_1Pin
J_PV+1: Conn_01x01; Banana_Jack_1Pin
J_PV-1: Conn_01x01; Banana_Jack_1Pin
J_Pump+1: Conn_01x01; Banana_Jack_1Pin
J_Pump-1: Conn_01x01; Banana_Jack_1Pin
J_VDD1+1, J_VDD1-1: Conn_01x01; Banana_Jack_1Pin

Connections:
/M1_Source: J_M1-1.1; also elsewhere on the board
/M3_Source: J_M3-1.1; also elsewhere on the board
/Pump_Voltage: J_Pump+1.1; also elsewhere on the board
/VDD1: J_VDD1+1.1; also elsewhere on the board
/V_M1+: J_M1+1.1; also elsewhere on the board
/V_M2+: J_M2+1.1; also elsewhere on the board
/V_M3+: J_M3+1.1; also elsewhere on the board
BAT+: J_BAT+1.1; also elsewhere on the board
PGND: J_BAT-1.1, J_M2-1.1, J_PV-1.1, J_Pump-1.1, J_VDD1-1.1; also elsewhere on the board
PV+: J_PV+1.1; also elsewhere on the board

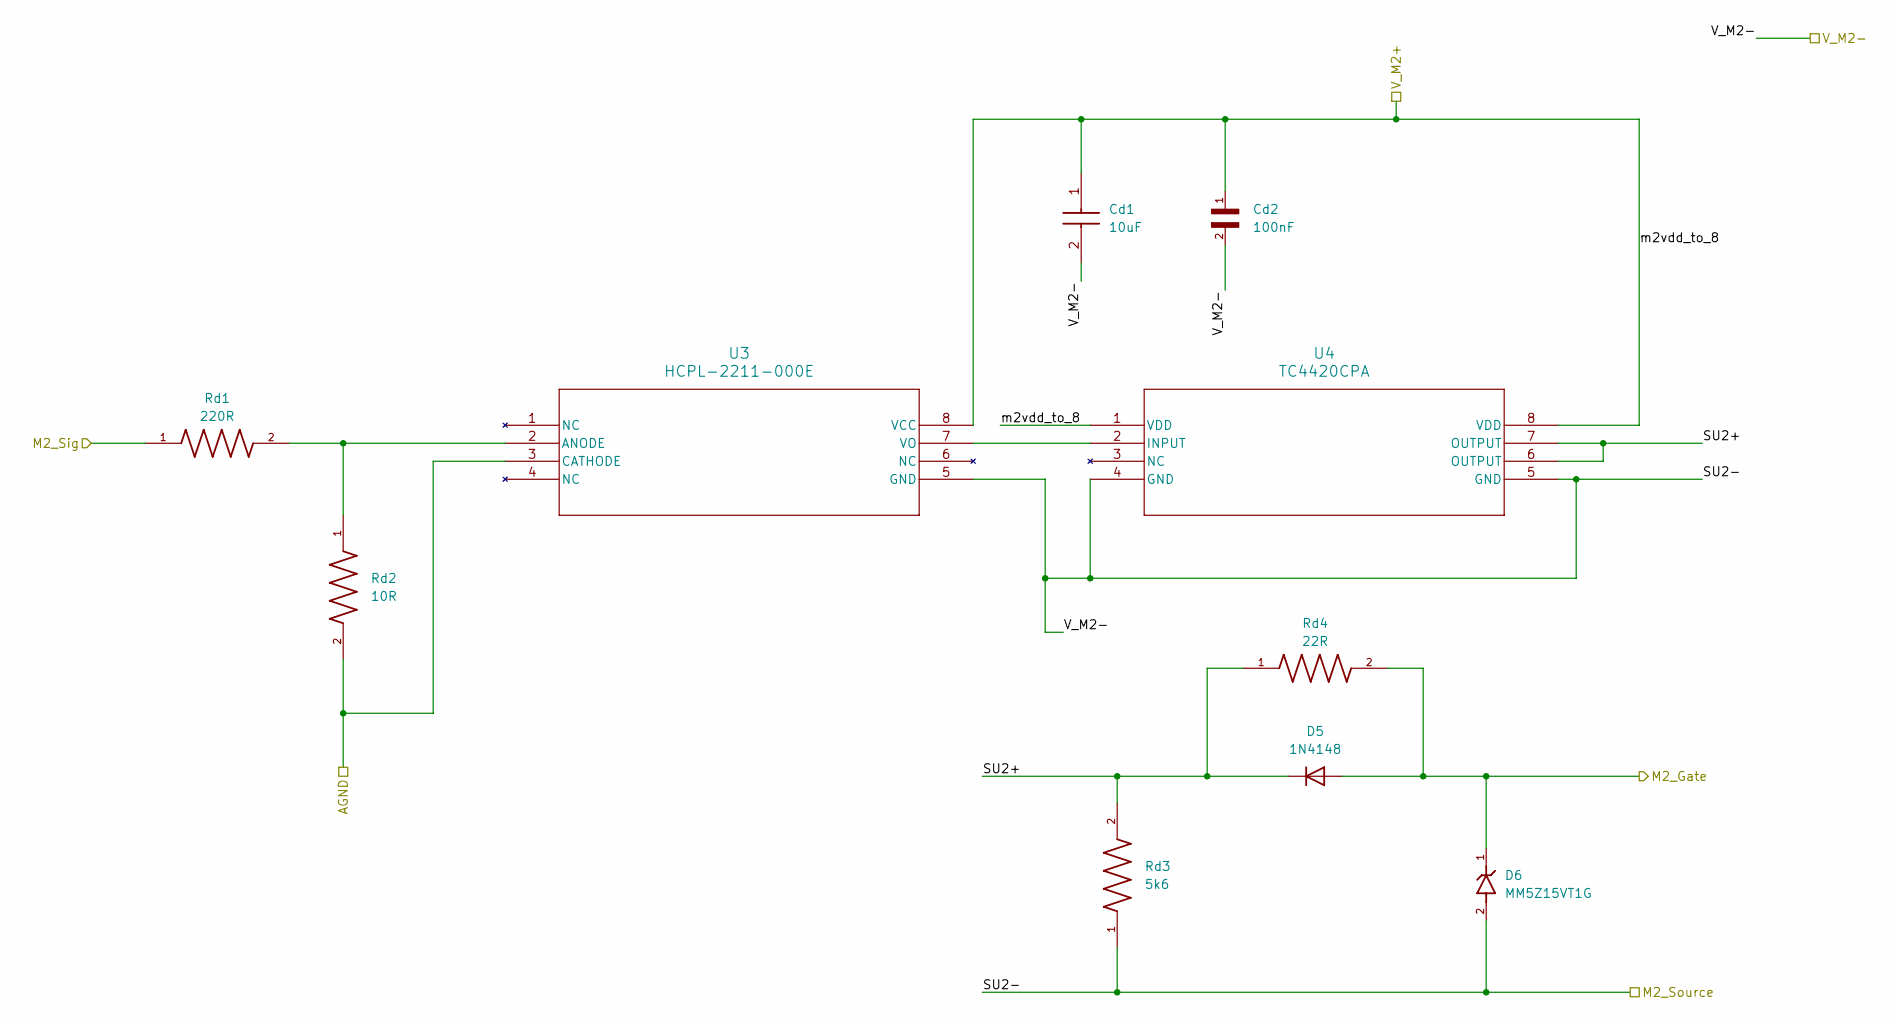
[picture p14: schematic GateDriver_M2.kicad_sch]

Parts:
Cd1: 10uF; CAPC3225X280N; Manufacturer_Part_Number AGC1210X7R500-106KNE
Cd2: 100nF; CAPC0603X33N
D5: 1N4148; D_DO-35_SOD27_P7.62mm_Horizontal
D6: MM5Z15VT1G; SODFL1608X70N; PARTREV 17
Rd1: 220R; RESC2012X60N
Rd2: 10R; RESC2012X60N
Rd3: 5k6; RESC2012X50N
Rd4: 22R; RESC2012X60N
U3: HCPL-2211-000E; SO-8_AVA
U4: TC4420CPA; PDIP8_300MC_MCH

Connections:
/GateDriver_M2/SU2+: D5.1 (K), Rd3.2, Rd4.1, U4.6 (OUTPUT), U4.7 (OUTPUT)
/M2_Gate: D5.2 (A), D6.1, Rd4.2; also elsewhere on the board
/M2_Sig: Rd1.1; also elsewhere on the board
/V_M2+: Cd1.1, Cd2.1, U3.8 (VCC), U4.1 (VDD), U4.8 (VDD); also elsewhere on the board
AGND: Rd2.2, U3.3 (CATHODE); also elsewhere on the board
unnamed: Rd1.2, Rd2.1, U3.2 (ANODE)
unnamed: U3.7 (VO), U4.2 (INPUT)
PGND: Cd1.2, Cd2.2, D6.2, Rd3.1, U3.5 (GND), U4.4 (GND), U4.5 (GND); also elsewhere on the board

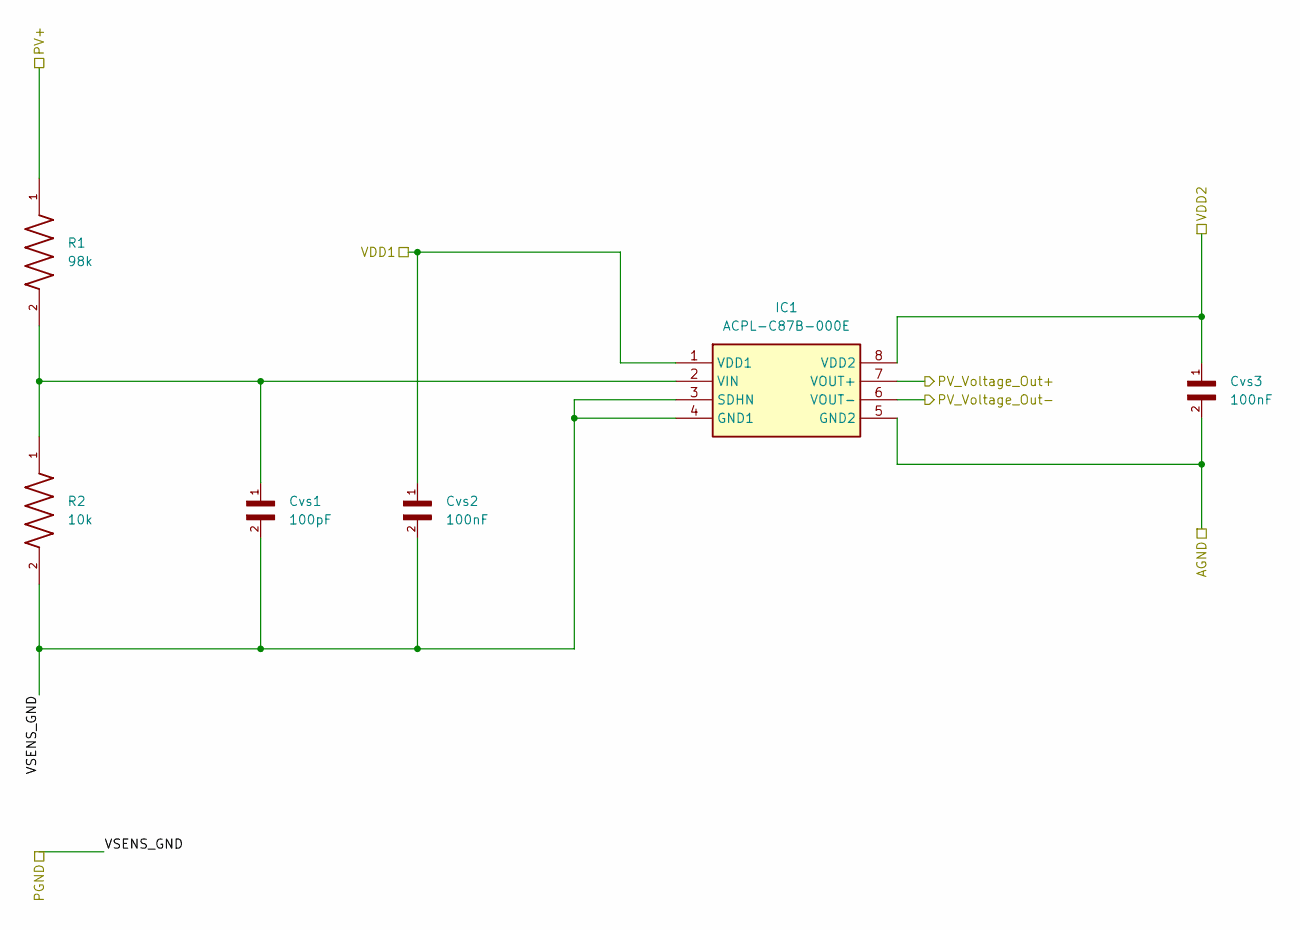
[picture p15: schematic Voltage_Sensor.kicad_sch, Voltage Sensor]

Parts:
Cvs1: 100pF; CAPC0603X33N
Cvs2, Cvs3: 100nF; CAPC0603X33N
IC1: ACPL-C87B-000E; SOIC127P1150X360-8N; Mouser Part Number 630-ACPL-C87B-000E
R1: 98k; RESC2012X60N
R2: 10k; RESC2012X60N

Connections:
/PV_Voltage_Out+: IC1.7 (VOUT+); also elsewhere on the board
/PV_Voltage_Out-: IC1.6 (VOUT-); also elsewhere on the board
/VCC: Cvs3.1, IC1.8 (VDD2); also elsewhere on the board
/VDD1: Cvs2.1, IC1.1 (VDD1); also elsewhere on the board
AGND: Cvs3.2, IC1.5 (GND2); also elsewhere on the board
unnamed: Cvs1.1, IC1.2 (VIN), R1.2, R2.1
PGND: Cvs1.2, Cvs2.2, IC1.3 (SDHN), IC1.4 (GND1), R2.2; also elsewhere on the board
PV+: R1.1; also elsewhere on the board

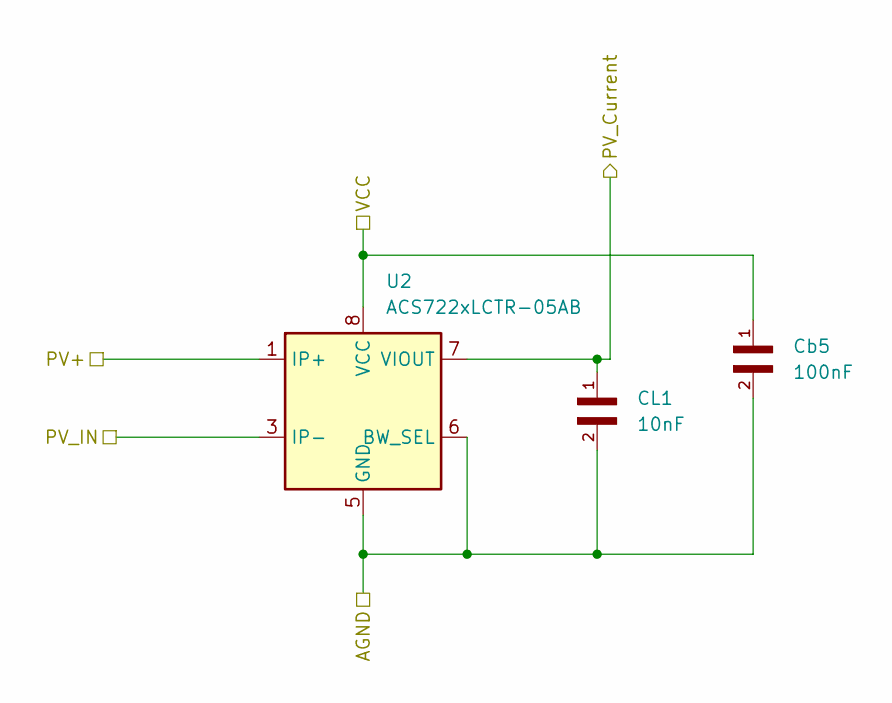
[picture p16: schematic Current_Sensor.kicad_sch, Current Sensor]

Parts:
CL1: 10nF; CAPC1005X55N
Cb5: 100nF; CAPC0603X33N
U2: ACS722xLCTR-05AB; SOIC-8_3.9x4.9mm_P1.27mm

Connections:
/PV_Current: CL1.1, U2.7 (VIOUT); also elsewhere on the board
/PV_IN: U2.3 (IP-), U2.4 (IP-); also elsewhere on the board
/VCC: Cb5.1, U2.8 (VCC); also elsewhere on the board
AGND: CL1.2, Cb5.2, U2.5 (GND), U2.6 (BW_SEL); also elsewhere on the board
PV+: U2.1 (IP+), U2.2 (IP+); also elsewhere on the board

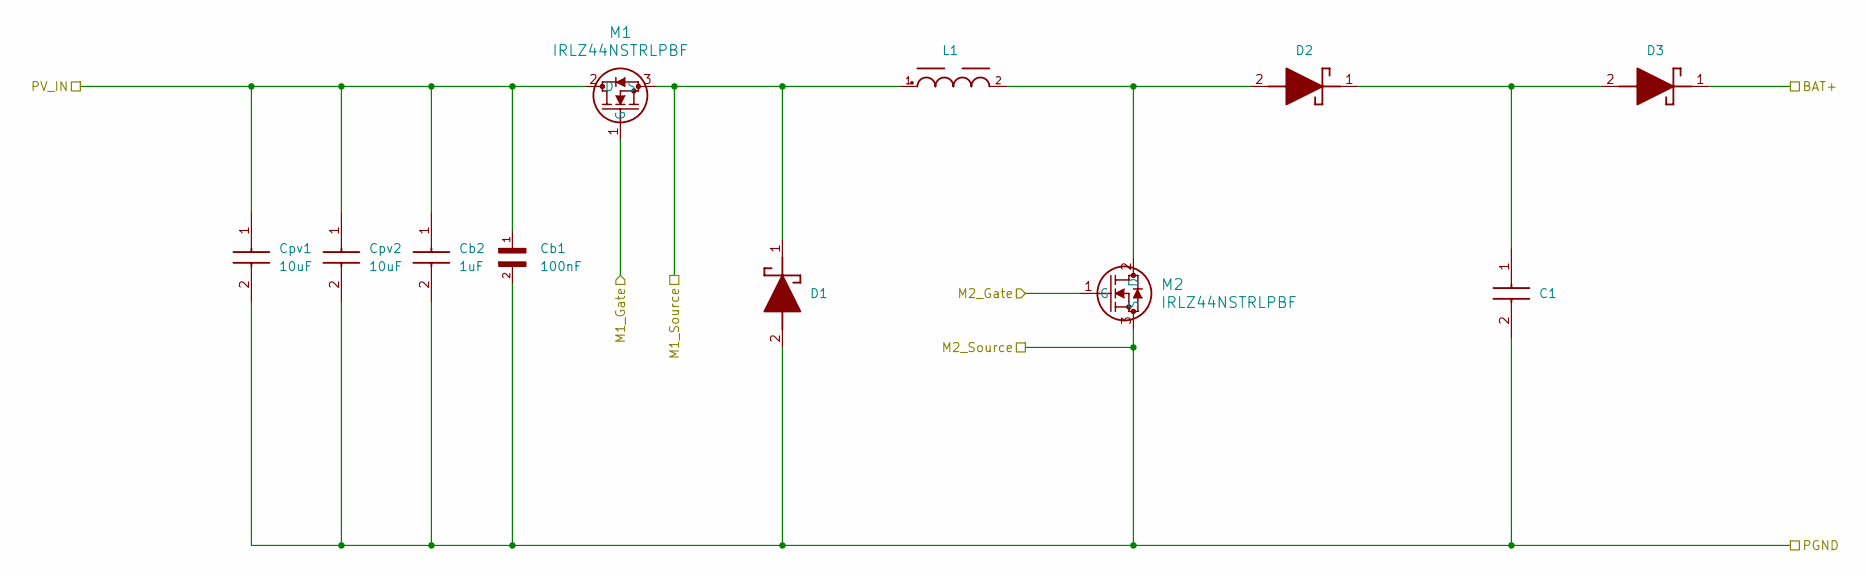
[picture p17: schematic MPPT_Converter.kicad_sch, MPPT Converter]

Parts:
C1: ATB107M035; CAPAE660X800N; Manufacturer_Part_Number ATB107M035; Mouser Part Number 598-ATB107M035
Cb1: 100nF; CAPC0603X33N
Cb2: 1uF; CAPC1608X95N; Manufacturer_Part_Number AGC0603X7R250-105KXP
Cpv1, Cpv2: 10uF; CAPC3225X280N; Manufacturer_Part_Number AGC1210X7R500-106KNE
D1, D2, D3: SK34SMA-3G; DIOM5027X240N; Manufacturer_Part_Number SK34SMA-3G; Mouser Part Number 637-SK34SMA-3G
L1: WE-HCF_2920_ROUND; DigiKey_Part_Number 732-11720-ND
M1, M2: IRLZ44NSTRLPBF; NMOSGDS_D2PAK_INF

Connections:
/M1_Gate: M1.1 (G); also elsewhere on the board
/M1_Source: D1.1 (K), L1.1, M1.3 (S); also elsewhere on the board
/M2_Gate: M2.1 (G); also elsewhere on the board
/PV_IN: Cb1.1, Cb2.1, Cpv1.1, Cpv2.1, M1.2 (D); also elsewhere on the board
BAT+: D3.1 (K); also elsewhere on the board
unnamed: C1.1 (+), D2.1 (K), D3.2 (A)
unnamed: D2.2 (A), L1.2, M2.2 (D)
PGND: C1.2 (-), Cb1.2, Cb2.2, Cpv1.2, Cpv2.2, D1.2 (A), M2.3 (S); also elsewhere on the board

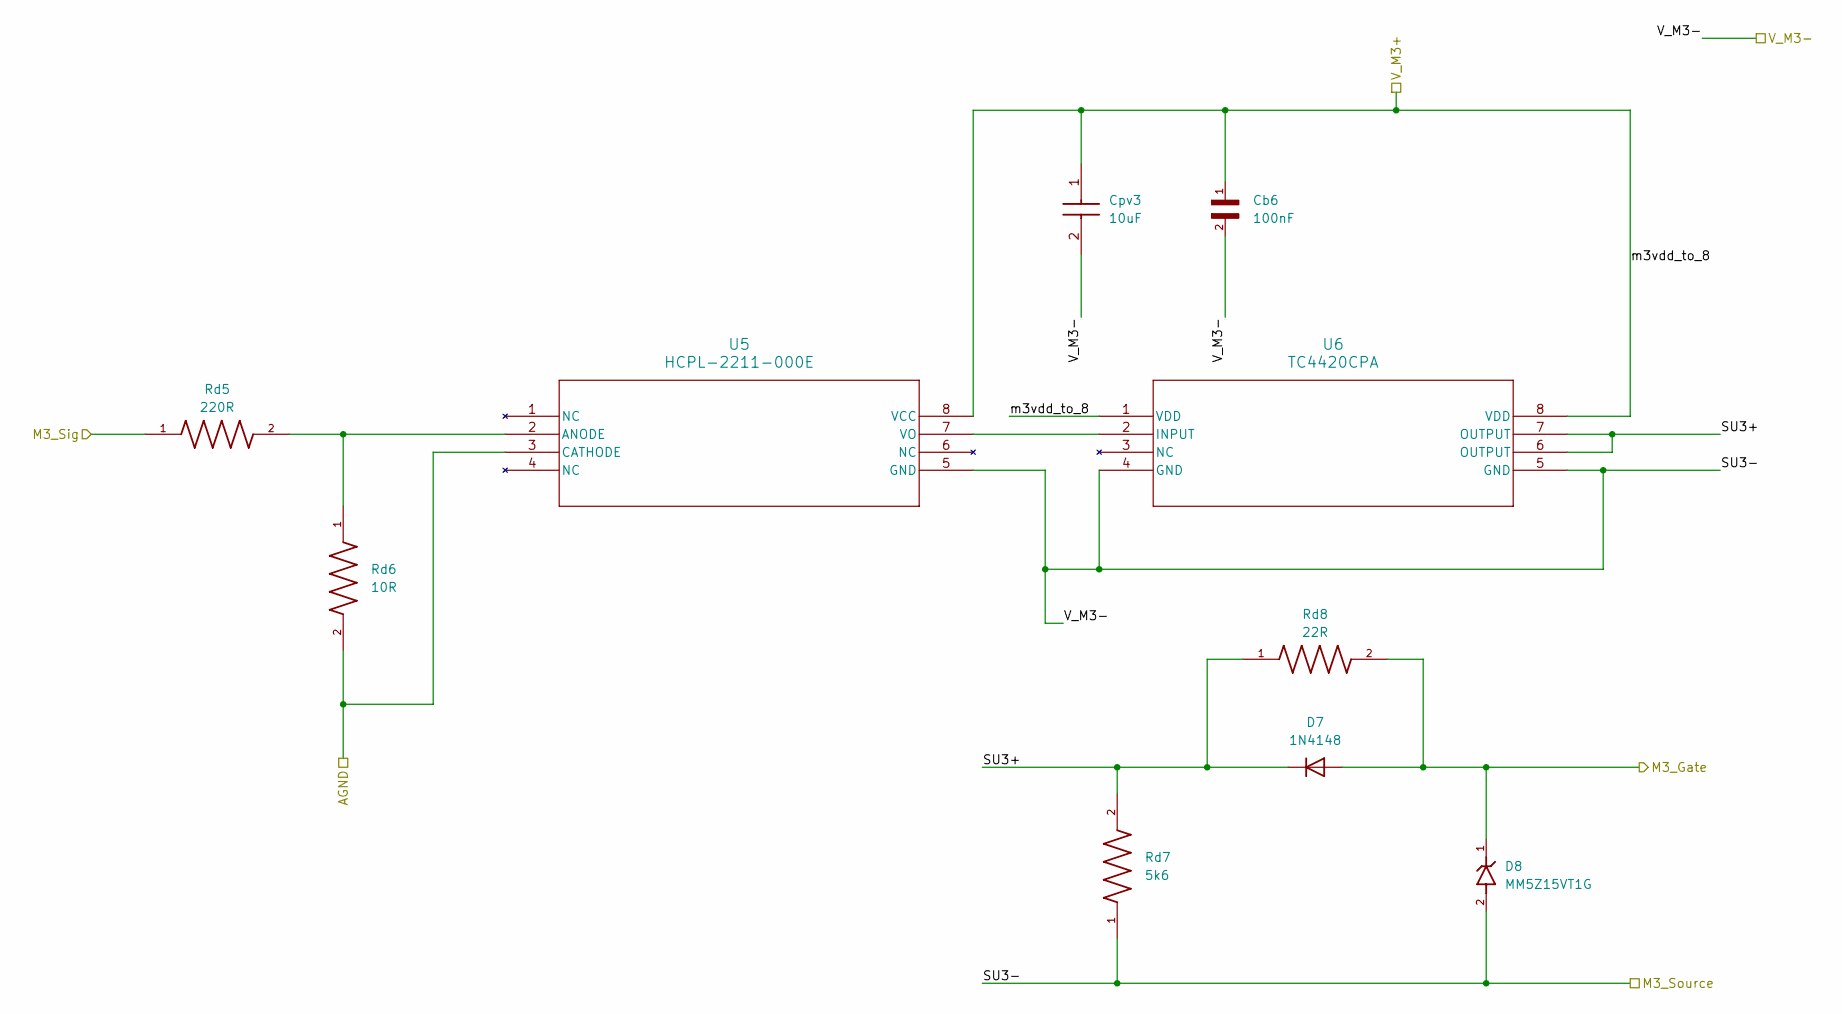
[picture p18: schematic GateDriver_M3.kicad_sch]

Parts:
Cb6: 100nF; CAPC0603X33N
Cpv3: 10uF; CAPC3225X280N; Manufacturer_Part_Number AGC1210X7R500-106KNE
D7: 1N4148; D_DO-35_SOD27_P7.62mm_Horizontal
D8: MM5Z15VT1G; SODFL1608X70N; PARTREV 17
Rd5: 220R; RESC2012X60N
Rd6: 10R; RESC2012X60N
Rd7: 5k6; RESC2012X50N
Rd8: 22R; RESC2012X60N
U5: HCPL-2211-000E; SO-8_AVA
U6: TC4420CPA; PDIP8_300MC_MCH

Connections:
/GateDriver_M3/SU3+: D7.1 (K), Rd7.2, Rd8.1, U6.6 (OUTPUT), U6.7 (OUTPUT)
/M3_Gate: D7.2 (A), D8.1, Rd8.2; also elsewhere on the board
/M3_Sig: Rd5.1; also elsewhere on the board
/M3_Source: Cb6.2, Cpv3.2, D8.2, Rd7.1, U5.5 (GND), U6.4 (GND), U6.5 (GND); also elsewhere on the board
/V_M3+: Cb6.1, Cpv3.1, U5.8 (VCC), U6.1 (VDD), U6.8 (VDD); also elsewhere on the board
AGND: Rd6.2, U5.3 (CATHODE); also elsewhere on the board
unnamed: Rd5.2, Rd6.1, U5.2 (ANODE)
unnamed: U5.7 (VO), U6.2 (INPUT)

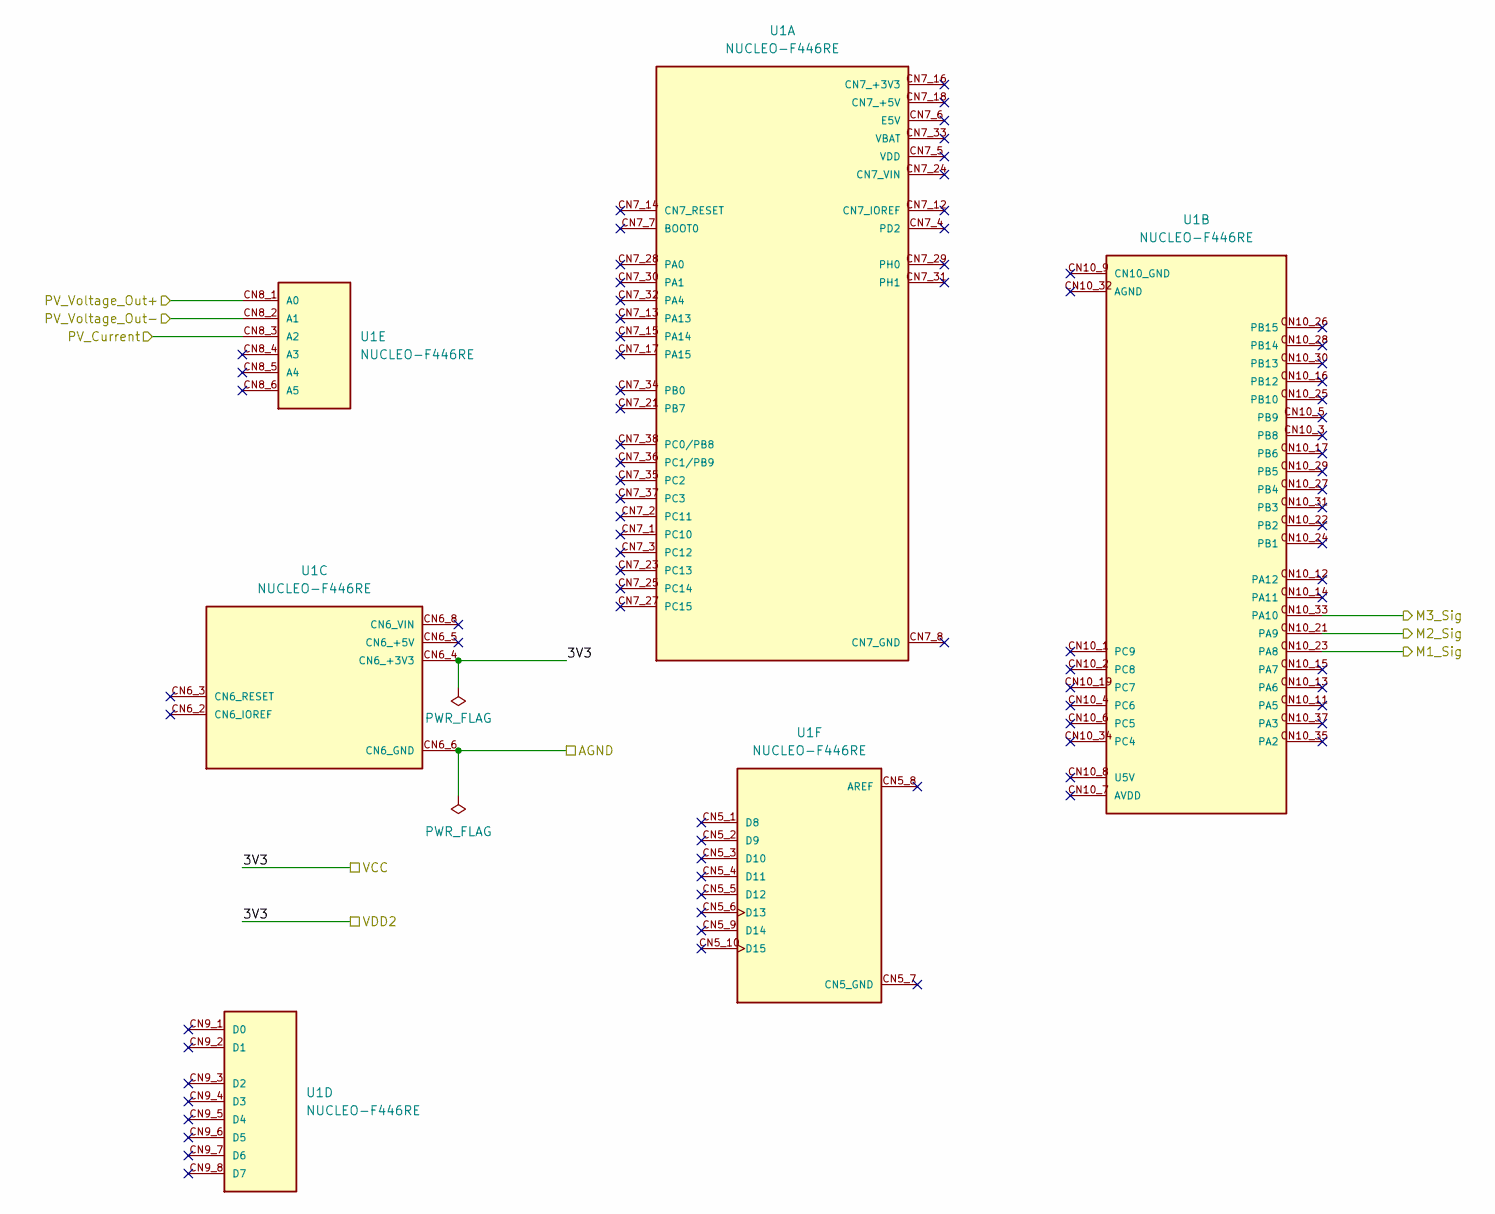
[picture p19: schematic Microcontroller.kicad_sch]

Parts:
U1: NUCLEO-F446RE; MODULE_NUCLEO-F446RE; PARTREV 13

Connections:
/M1_Sig: U1.CN10_23 (PA8); also elsewhere on the board
/M2_Sig: U1.CN10_21 (PA9); also elsewhere on the board
/M3_Sig: U1.CN10_33 (PA10); also elsewhere on the board
/PV_Current: U1.CN8_3 (A2); also elsewhere on the board
/PV_Voltage_Out+: U1.CN8_1 (A0); also elsewhere on the board
/PV_Voltage_Out-: U1.CN8_2 (A1); also elsewhere on the board
/VCC: U1.CN6_4 (CN6_+3V3); also elsewhere on the board
AGND: U1.CN6_6 (CN6_GND), U1.CN6_7 (CN6_GND); also elsewhere on the board

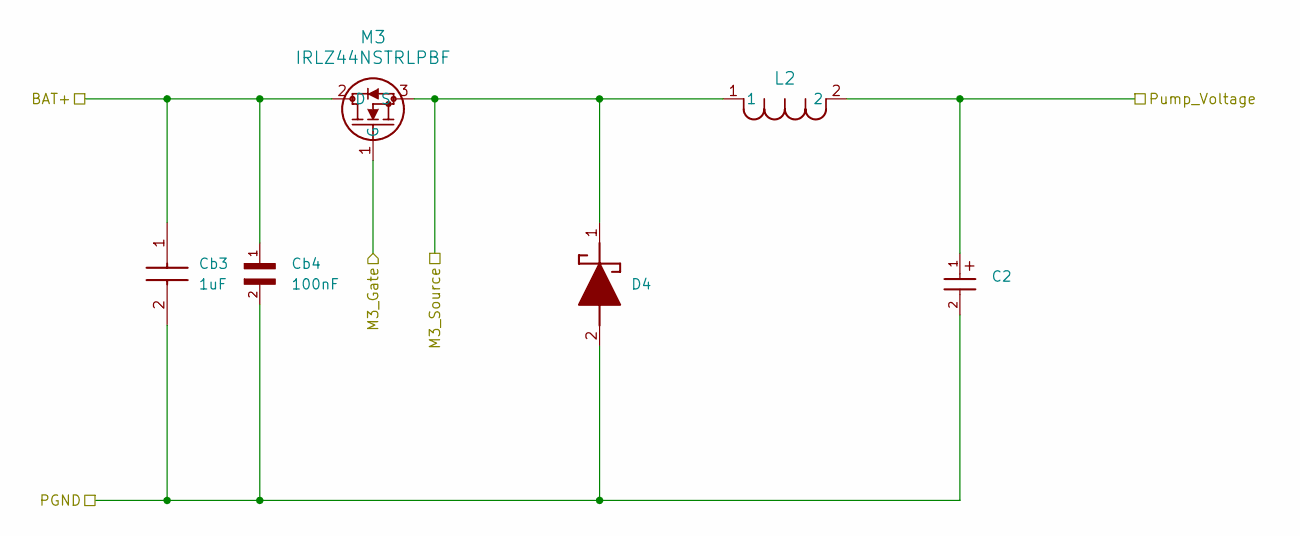
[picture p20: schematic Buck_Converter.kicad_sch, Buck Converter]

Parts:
C2: WCAP-ASLI_4X5.5; WCAP-ASLI_4X5.5_DXL_
Cb3: 1uF; CAPC1608X95N; Manufacturer_Part_Number AGC0603X7R250-105KXP
Cb4: 100nF; CAPC0603X33N
D4: SK34SMA-3G; DIOM5027X240N; Manufacturer_Part_Number SK34SMA-3G; Mouser Part Number 637-SK34SMA-3G
L2: SRR1210-471M; IND_BOURNS_SRR1210
M3: IRLZ44NSTRLPBF; NMOSGDS_D2PAK_INF

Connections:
/M3_Gate: M3.1 (G); also elsewhere on the board
/M3_Source: D4.1 (K), L2.1, M3.3 (S); also elsewhere on the board
/Pump_Voltage: C2.1, L2.2; also elsewhere on the board
BAT+: Cb3.1, Cb4.1, M3.2 (D); also elsewhere on the board
PGND: C2.2, Cb3.2, Cb4.2, D4.2 (A); also elsewhere on the board

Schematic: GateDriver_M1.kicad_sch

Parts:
Cd3: 10uF; CAPC3225X280N; Manufacturer_Part_Number AGC1210X7R500-106KNE
Cd4: 100nF; CAPC0603X33N
D9: 1N4148; D_DO-35_SOD27_P7.62mm_Horizontal
D10: MM5Z15VT1G; SODFL1608X70N; PARTREV 17
Rd9: 220R; RESC2012X60N
Rd10: 10R; RESC2012X60N
Rd11: 5k6; RESC2012X50N
Rd12: 22R; RESC2012X60N
U7: HCPL-2211-000E; SO-8_AVA
U8: TC4420CPA; PDIP8_300MC_MCH

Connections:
/GateDriver_M1/SU1+: D9.1 (K), Rd11.2, Rd12.1, U8.6 (OUTPUT), U8.7 (OUTPUT)
/M1_Gate: D9.2 (A), D10.1, Rd12.2; also elsewhere on the board
/M1_Sig: Rd9.1; also elsewhere on the board
/M1_Source: Cd3.2, Cd4.2, D10.2, Rd11.1, U7.5 (GND), U8.4 (GND), U8.5 (GND); also elsewhere on the board
/V_M1+: Cd3.1, Cd4.1, U7.8 (VCC), U8.1 (VDD), U8.8 (VDD); also elsewhere on the board
AGND: Rd10.2, U7.3 (CATHODE); also elsewhere on the board
unnamed: Rd9.2, Rd10.1, U7.2 (ANODE)
unnamed: U7.7 (VO), U8.2 (INPUT)

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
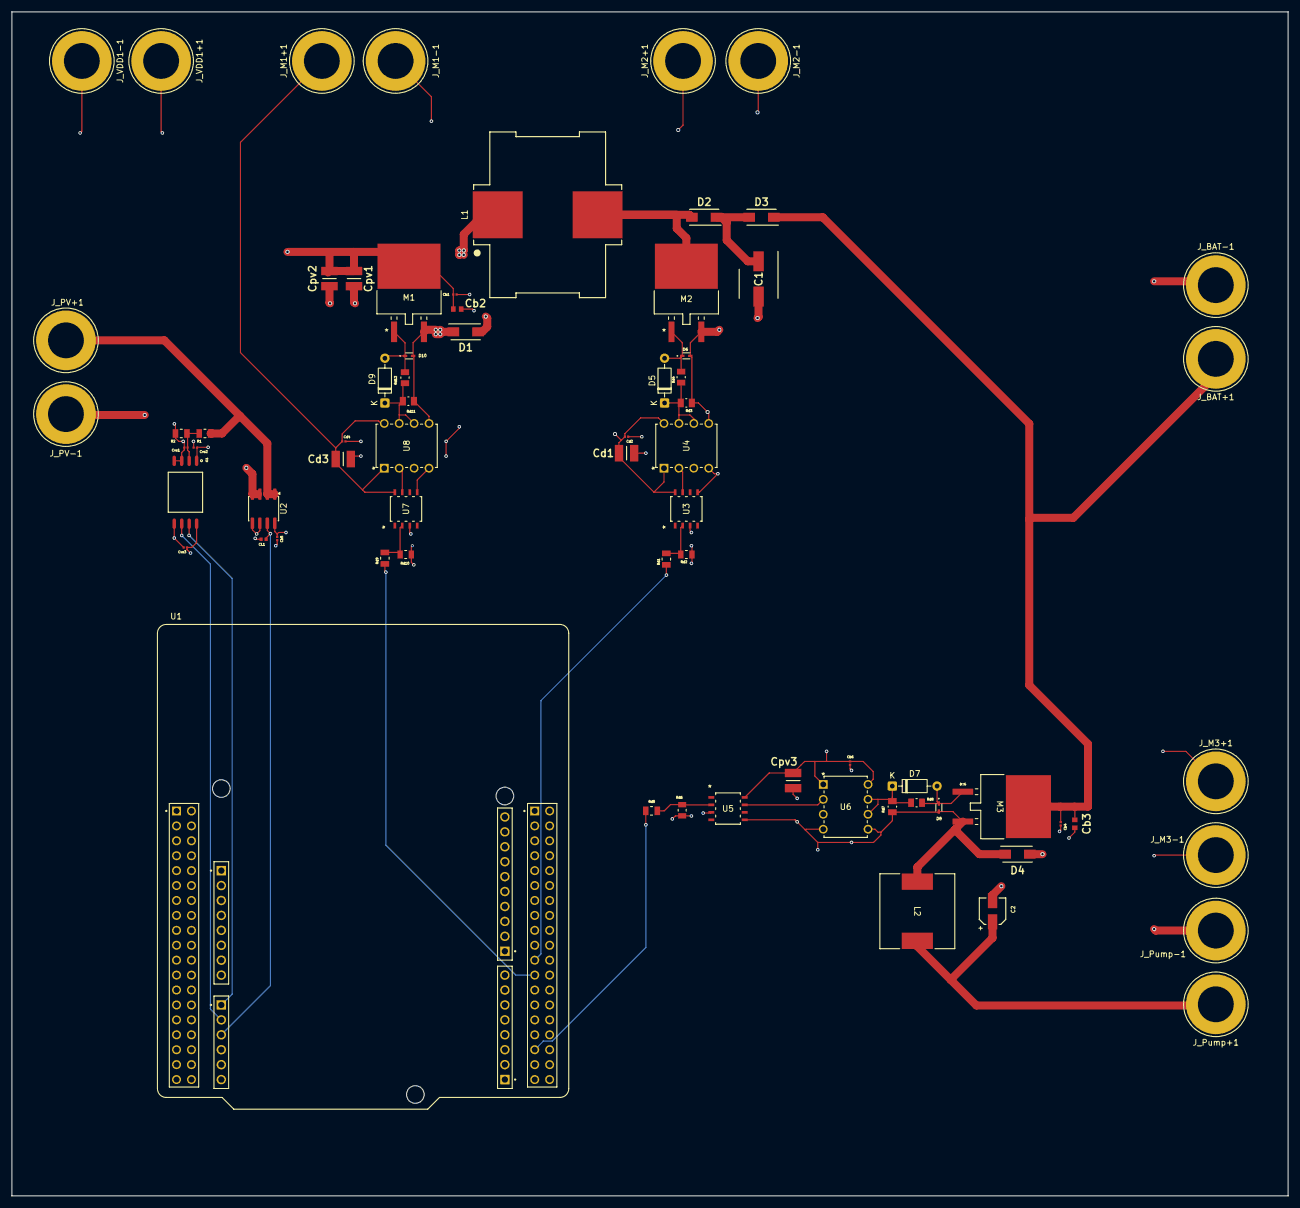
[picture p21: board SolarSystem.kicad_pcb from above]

Board: 4 copper layers, 217.2 x 201.5 mm, 71 parts (0 on the bottom side), 34 nets.

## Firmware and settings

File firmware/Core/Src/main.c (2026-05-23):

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
/* Includes ------------------------------------------------------------------*/
#include "main.h"

/* USER CODE BEGIN Includes */
#include <stdio.h>
#include <string.h>
/* USER CODE END Includes */

ADC_HandleTypeDef hadc1;
ADC_HandleTypeDef hadc2;
ADC_HandleTypeDef hadc3;
DMA_HandleTypeDef hdma_adc1;

TIM_HandleTypeDef htim1;

UART_HandleTypeDef huart2;

/* USER CODE BEGIN PV */
#define ADC_BUF_LEN 64
#define ADC_MAX_COUNTS      4095.0f
#define ADC_VREF            3.3f      // STM32 VREF+ — used for ALL ADC conversions

/* Soil moisture sensor (DFRobot SEN0308 on PC3 / ADC3_IN11) */
#define MOISTURE_AIR_VALUE      3665   // CALIBRATE: raw ADC value in dry air
#define MOISTURE_WATER_VALUE    540   // CALIBRATE: raw ADC value submerged in water
#define MOISTURE_INTERVALS      ((MOISTURE_AIR_VALUE - MOISTURE_WATER_VALUE) / 3)

/* Pump speed control (M3 = TIM1 CH3) */
typedef enum {
    PUMP_OFF  = 0,
    PUMP_SLOW = 50,    // ~6V at 12V battery
    PUMP_FAST = 75,    // ~9V at 12V battery
    PUMP_FULL = 100    // 12V (demo only)
} PumpSpeed_t;

// Voltage sensor signal chain:
//   Vbus -> divider (R1=98.8k top, R2=10k bottom) -> ACPL-C87X (gain=1)
//        -> OPA237 diff amp (gain=1) -> STM32 ADC pin
// So: V_adc_pin = Vbus * R2 / (R1+R2) = Vbus / 10.88
#define VDIV_RTOP           98800.0f
#define VDIV_RBOT           10000.0f
#define VDIV_SCALE          ((VDIV_RTOP + VDIV_RBOT) / VDIV_RBOT)  // = 10.88
#define VOLTAGE_OFFSET      0.0002f   //

// Current sensor (ACS722, bidirectional, 3.3V supply):
//   VIOUT_Q = VCC/2 = 1.65V at zero current

#define ACS_ZERO_V          1.6328f   //
#define ACS_SENS_V_PER_A    0.2640f   // adjust if you have a different variant

static uint32_t override_until_tick = 0;

uint32_t adc_buffer[ADC_BUF_LEN];

volatile uint64_t v_sum = 0;
volatile uint64_t i_sum = 0;
volatile uint32_t sample_count = 0;

uint32_t last_print = 0;

/* =========================
 * Control mode selection
 * ========================= */

#define CONTROL_MANUAL             0
#define CONTROL_IV_SWEEP           1
#define CONTROL_MPPT               2
#define CONTROL_SOIL_ONLY          3
#define CONTROL_MPPT_AND_SOIL      4

/*
 * Select your current operating mode here.
 *
 * CONTROL_MANUAL:
 *      M1/M2/M3 use manual duty values.
 *
 * CONTROL_IV_SWEEP:
 *      M1/M2 sweep through iv_duty_list.
 *      M3 is pump off for safety.
 *
 * CONTROL_MPPT:
 *      MPPT will control M1/M2.
 *      M3 uses manual duty unless ENABLE_SOIL_MOISTURE is 1.
 *
 * CONTROL_SOIL_ONLY:
 *      M1/M2 manual.
 *      M3 controlled by soil moisture.
 *
 * CONTROL_MPPT_AND_SOIL:
 *      MPPT controls M1/M2.
 *      Soil moisture controls M3.
 */
#define CONTROL_MODE CONTROL_MPPT

/*
 * Independent enable for soil moisture pump control.
 * This is automatically used in CONTROL_SOIL_ONLY and CONTROL_MPPT_AND_SOIL.
 * You can also enable it with CONTROL_MPPT if desired.
 */
#define ENABLE_SOIL_MOISTURE      0

/* Manual duty settings */
#define MANUAL_M1_DUTY            30u
#define MANUAL_M2_DUTY            30u
#define MANUAL_M3_DUTY            70u

/* Live sensor print timing */
#define SENSOR_PRINT_TIME_MS      500u

/* =========================
 * Automatic IV sweep settings
 * ========================= */

#define IV_SETTLE_TIME_MS         500u
#define IV_MEASURE_TIME_MS        1000u

static const uint8_t iv_duty_list[] = {
	93, 81, 72, 65, 59,
    55, 52, 50, 48, 46,
    45, 44, 43, 42, 41,
    40, 39, 38, 37, 36,
    35, 34, 33, 32, 30
};

#define IV_NUM_POINTS   (sizeof(iv_duty_list) / sizeof(iv_duty_list[0]))

typedef enum {
    IV_SWEEP_IDLE = 0,
    IV_SWEEP_SET_DUTY,
    IV_SWEEP_SETTLE,
    IV_SWEEP_MEASURE,
    IV_SWEEP_PRINT,
    IV_SWEEP_DONE
} IV_SweepState_t;

static IV_SweepState_t iv_state = IV_SWEEP_SET_DUTY;
static uint32_t iv_state_tick = 0;
static uint8_t iv_index = 0;

/* Sums used only for one sweep operating point */
static uint64_t iv_v_sum = 0;
static uint64_t iv_i_sum = 0;
static uint32_t iv_count = 0;

/* Latest soil moisture / pump status */
static uint16_t latest_moisture_raw = 0;
static const char* latest_moisture_label = "N/A";
static PumpSpeed_t latest_pump_speed = PUMP_OFF;
static uint8_t soil_data_valid = 0;

/* =========================
 * MPPT placeholder variables
 * ========================= */

/* =========================
 * MPPT Perturb & Observe settings
 * ========================= */

#define MPPT_UPDATE_TIME_MS       500u

#define MPPT_DUTY_MIN             30u
#define MPPT_DUTY_MAX             93u
#define MPPT_DUTY_START           45u
#define MPPT_DUTY_STEP            1u

#define MPPT_TRACK_DURATION_MS        20000u
#define MPPT_FINAL_AVG_WINDOW_MS      5000u
#define MPPT_TRACK_SETTLE_MS          500u

/*
 * Small threshold to avoid reacting to sensor noise.
 * If power change is smaller than this, duty is not changed.
 */
#define MPPT_POWER_DEADBAND_W     0.03f

static uint8_t mppt_duty = MPPT_DUTY_START;
static int8_t mppt_direction = 1;   // +1 means increase duty, -1 means decrease duty
static float mppt_prev_power = 0.0f;
static float mppt_prev_voltage = 0.0f;
static float mppt_prev_current = 0.0f;
static uint8_t mppt_initialized = 0;
static uint32_t last_mppt_tick = 0;

/* USER CODE END PV */

void SystemClock_Config(void);
static void MX_GPIO_Init(void);
static void MX_DMA_Init(void);
static void MX_USART2_UART_Init(void);
static void MX_TIM1_Init(void);
static void MX_ADC1_Init(void);
static void MX_ADC2_Init(void);
static void MX_ADC3_Init(void);
/* USER CODE BEGIN PFP */

void find_calibration_values(void);
void find_moisture_calibration(void);

void Set_Converter_Duty(uint8_t duty_percent);
void Set_Manual_Duties(void);
void Read_Panel_Sensors(float *panel_voltage,
                        float *panel_current,
                        float *panel_power,
                        float *v_pin_out,
                        uint32_t *sample_n);
void Print_Panel_Sensors(void);
void Run_IV_Sweep(void);
void Run_MPPT(void);
void Run_Soil_Moisture_Control(void);
void track_mpp_20_seconds(uint8_t start_duty);

/* USER CODE END PFP */

/* USER CODE BEGIN 0 */
void Process_ADC_Buffer(uint32_t *buffer, uint32_t length)
{
    for (uint32_t n = 0; n < length; n++)
    {
        uint32_t combined = buffer[n];

        uint16_t voltage_raw = combined & 0xFFFF;
        uint16_t current_raw = (combined >> 16) & 0xFFFF;

        v_sum += voltage_raw;
        i_sum += current_raw;
        sample_count++;
    }
}

uint16_t Read_Moisture(void)
{
    // Clear any leftover OVR/EOC flags from the previous conversion
    ADC3->SR = 0;

    // Manually trigger a single conversion
    ADC3->CR2 |= ADC_CR2_SWSTART;

    // Wait for conversion to complete (with timeout)
    uint32_t timeout = HAL_GetTick() + 10;
    while ((ADC3->SR & ADC_SR_EOC) == 0)
    {
        if (HAL_GetTick() > timeout) {
            return 0xFFFF;  // timeout sentinel
        }
    }

    // Read the value (this also clears EOC automatically)
    return (uint16_t)ADC3->DR;
}

const char* Classify_Moisture(uint16_t value)
{
    if (value > MOISTURE_AIR_VALUE)
        return "Very Dry / Air";
    if (value > (MOISTURE_AIR_VALUE - MOISTURE_INTERVALS))
        return "Dry";
    if (value > (MOISTURE_WATER_VALUE + MOISTURE_INTERVALS))
        return "Wet";
    if (value > MOISTURE_WATER_VALUE)
        return "Very Wet";
    return "Submerged";
}

PumpSpeed_t Decide_Pump_Speed(uint16_t moisture_raw)
{
    const uint16_t AIR_MARGIN = 100;  // counts of margin below air calibration

    // Sensor in dry air (or above) -> pump off (safety)
    if (moisture_raw >= (MOISTURE_AIR_VALUE - AIR_MARGIN))   return PUMP_OFF;

    // Below water calibration -> already submerged, pump off (safety)
    if (moisture_raw < MOISTURE_WATER_VALUE) return PUMP_OFF;

    // Within calibrated range -> decide based on dryness
    if (moisture_raw > (MOISTURE_AIR_VALUE - MOISTURE_INTERVALS)) {
        return PUMP_FAST;     // Dry soil
    }
    if (moisture_raw > (MOISTURE_WATER_VALUE + MOISTURE_INTERVALS)) {
        return PUMP_SLOW;     // Moist soil
    }
    return PUMP_OFF;          // Already wet enough
}

void Set_Pump_Speed(PumpSpeed_t speed)
{
    uint32_t arr = __HAL_TIM_GET_AUTORELOAD(&htim1);
    __HAL_TIM_SET_COMPARE(&htim1, TIM_CHANNEL_3, ((uint32_t)speed * arr) / 100);
}

void Set_Converter_Duty(uint8_t duty_percent)
{
    if (duty_percent > 100) {
        duty_percent = 100;
    }

    uint32_t arr = __HAL_TIM_GET_AUTORELOAD(&htim1);

    /*
     * MPPT and IV sweep both control M1 and M2 together.
     */
    __HAL_TIM_SET_COMPARE(&htim1, TIM_CHANNEL_1, ((uint32_t)duty_percent * arr) / 100);
    __HAL_TIM_SET_COMPARE(&htim1, TIM_CHANNEL_2, ((uint32_t)duty_percent * arr) / 100);
}

void Set_Manual_Duties(void)
{
    uint32_t arr = __HAL_TIM_GET_AUTORELOAD(&htim1);

    __HAL_TIM_SET_COMPARE(&htim1, TIM_CHANNEL_1, ((uint32_t)MANUAL_M1_DUTY * arr) / 100);
    __HAL_TIM_SET_COMPARE(&htim1, TIM_CHANNEL_2, ((uint32_t)MANUAL_M2_DUTY * arr) / 100);
    __HAL_TIM_SET_COMPARE(&htim1, TIM_CHANNEL_3, ((uint32_t)MANUAL_M3_DUTY * arr) / 100);
}

void Read_Panel_Sensors(float *panel_voltage,
                        float *panel_current,
                        float *panel_power,
                        float *v_pin_out,
                        uint32_t *sample_n)
{
    __disable_irq();
    uint64_t v_sum_copy = v_sum;
    uint64_t i_sum_copy = i_sum;
    uint32_t count_copy = sample_count;

    v_sum = 0;
    i_sum = 0;
    sample_count = 0;
    __enable_irq();

    if (sample_n != NULL) {
        *sample_n = count_copy;
    }

    if (count_copy == 0)
    {
        if (panel_voltage != NULL) *panel_voltage = 0.0f;
        if (panel_current != NULL) *panel_current = 0.0f;
        if (panel_power   != NULL) *panel_power   = 0.0f;
        if (v_pin_out     != NULL) *v_pin_out     = 0.0f;
        return;
    }

    float v_adc_avg = (float)v_sum_copy / (float)count_copy;
    float i_adc_avg = (float)i_sum_copy / (float)count_copy;

    float v_pin = (v_adc_avg / ADC_MAX_COUNTS) * ADC_VREF;
    float i_pin = (i_adc_avg / ADC_MAX_COUNTS) * ADC_VREF;

    float v_compensated = v_pin - VOLTAGE_OFFSET;
    float v_panel = v_compensated * VDIV_SCALE;

    float i_panel = (i_pin - ACS_ZERO_V) / ACS_SENS_V_PER_A;

    /*
     * If current polarity is reversed, use:
     * float i_panel = (ACS_ZERO_V - i_pin) / ACS_SENS_V_PER_A;
     */

    float p_panel = v_panel * i_panel;

    if (panel_voltage != NULL) *panel_voltage = v_panel;
    if (panel_current != NULL) *panel_current = i_panel;
    if (panel_power   != NULL) *panel_power   = p_panel;
    if (v_pin_out     != NULL) *v_pin_out     = v_pin;
}

void Print_Panel_Sensors(void)
{
    if ((HAL_GetTick() - last_print) >= SENSOR_PRINT_TIME_MS)
    {
        float panel_voltage = 0.0f;
        float panel_current = 0.0f;
        float panel_power = 0.0f;
        uint32_t sample_n = 0;

        Read_Panel_Sensors(&panel_voltage,
                           &panel_current,
                           &panel_power,
                           NULL,
                           &sample_n);

        if (sample_n > 0)
        {
            char msg[240];

#if (CONTROL_MODE == CONTROL_SOIL_ONLY) || (CONTROL_MODE == CONTROL_MPPT_AND_SOIL) || ((CONTROL_MODE == CONTROL_MPPT) && ENABLE_SOIL_MOISTURE)

            if (soil_data_valid)
            {
                snprintf(msg, sizeof(msg),
                         "Vpanel: %.2f V, I: %.3f A, P: %.2f W | Moisture: %u (%s) | Pump: %u%% (n=%lu)\r\n",
                         panel_voltage,
                         panel_current,
                         panel_power,
                         latest_moisture_raw,
                         latest_moisture_label,
                         (unsigned int)latest_pump_speed,
                         (unsigned long)sample_n);
            }
            else
            {
                snprintf(msg, sizeof(msg),
                         "Vpanel: %.2f V, I: %.3f A, P: %.2f W | Moisture: waiting... (n=%lu)\r\n",
                         panel_voltage,
                         panel_current,
                         panel_power,
                         (unsigned long)sample_n);
            }

#else

            snprintf(msg, sizeof(msg),
                     "D: %u%%, Vpanel: %.2f V, I: %.3f A, P: %.2f W (n=%lu)\r\n",
                     (unsigned int)mppt_duty,
                     panel_voltage,
                     panel_current,
                     panel_power,
                     (unsigned long)sample_n);

#endif

            HAL_UART_Transmit(&huart2, (uint8_t*)msg, strlen(msg), 100);
        }

        last_print = HAL_GetTick();
    }
}

void Run_Soil_Moisture_Control(void)
{
    static uint32_t last_soil_tick = 0;

    /*
     * Soil moisture does not need to run very fast.
     * 500 ms is enough for pump control.
     */
    if ((HAL_GetTick() - last_soil_tick) >= 500u)
    {
    	uint16_t moisture_raw = Read_Moisture();
    	const char* moisture_label = Classify_Moisture(moisture_raw);

    	PumpSpeed_t pump_speed;

    	if (HAL_GPIO_ReadPin(B1_GPIO_Port, B1_Pin) == GPIO_PIN_RESET)
    	{
    	    override_until_tick = HAL_GetTick() + 5000;
    	}

    	if (HAL_GetTick() < override_until_tick)
    	{
    	    pump_speed = PUMP_FULL;
    	    HAL_GPIO_WritePin(LD2_GPIO_Port, LD2_Pin, GPIO_PIN_SET);
    	}
    	else
    	{
    	    pump_speed = Decide_Pump_Speed(moisture_raw);
    	    HAL_GPIO_WritePin(LD2_GPIO_Port, LD2_Pin, GPIO_PIN_RESET);
    	}

    	Set_Pump_Speed(pump_speed);

    	/* Save latest soil/pump values for printing */
    	latest_moisture_raw = moisture_raw;
    	latest_moisture_label = moisture_label;
    	latest_pump_speed = pump_speed;
    	soil_data_valid = 1;

    	last_soil_tick = HAL_GetTick();
    }
}
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
int main(void)
{

  /* MCU Configuration--------------------------------------------------------*/

  /* Reset of all peripherals, Initializes the Flash interface and the Systick. */
  HAL_Init();

  /* Configure the system clock */
  SystemClock_Config();

  /* Initialize all configured peripherals */
  MX_GPIO_Init();
  MX_DMA_Init();
  MX_USART2_UART_Init();
  MX_TIM1_Init();
  MX_ADC1_Init();
  MX_ADC2_Init();
  MX_ADC3_Init();
  /* USER CODE BEGIN 2 */

  char msg[] = "UART WORKING\r\n";
  HAL_UART_Transmit(&huart2, (uint8_t*)msg, strlen(msg), 100);

  // Start timer base
  HAL_TIM_Base_Start(&htim1);

  // Start PWM on all 3 channels
  HAL_TIM_PWM_Start(&htim1, TIM_CHANNEL_1);
  HAL_TIM_PWM_Start(&htim1, TIM_CHANNEL_2);
  HAL_TIM_PWM_Start(&htim1, TIM_CHANNEL_3);

  Set_Pump_Speed(PUMP_OFF);  //
  HAL_TIM_OC_Start(&htim1, TIM_CHANNEL_1);

  HAL_ADC_Start(&hadc1);  // Start ADC1 first
  HAL_ADC_Start(&hadc2);  // Start ADC2

  if (HAL_ADCEx_MultiModeStart_DMA(&hadc1, adc_buffer, ADC_BUF_LEN) != HAL_OK)
  {
      Error_Handler();
  }
  HAL_ADC_Start(&hadc3); // Start ADC3

  // Initial duty setup

  Set_Manual_Duties();

  #if CONTROL_MODE == CONTROL_IV_SWEEP
  char csv_header[] = "\r\nPoint,Duty_percent,Vpanel_V,Ipanel_A,Ppanel_W,Samples\r\n";
  HAL_UART_Transmit(&huart2, (uint8_t*)csv_header, strlen(csv_header), 100);
  #endif

  // find_calibration_values();
  // find_moisture_calibration();
  track_mpp_20_seconds(35);

  /* USER CODE END 2 */

  /* Infinite loop */
  /* USER CODE BEGIN WHILE */
  while (1)
  {
    /* USER CODE BEGIN 3 */

  #if CONTROL_MODE == CONTROL_MANUAL

      /*
       * Manual mode:
       * M1, M2, and M3 are set by MANUAL_M1_DUTY,
       * MANUAL_M2_DUTY, and MANUAL_M3_DUTY.
       */
      Set_Manual_Duties();
      Print_Panel_Sensors();

  #elif CONTROL_MODE == CONTROL_IV_SWEEP

      /*
       * IV sweep mode:
       * M1/M2 are swept through iv_duty_list.
       * M3 is kept off inside Run_IV_Sweep().
       */
      Run_IV_Sweep();

  #elif CONTROL_MODE == CONTROL_MPPT

      /*
       * MPPT mode:
       * MPPT controls M1/M2.
       * M3 stays manual unless ENABLE_SOIL_MOISTURE is set.
       */
      Run_MPPT();

      #if ENABLE_SOIL_MOISTURE
          Run_Soil_Moisture_Control();
      #else
          Set_Pump_Speed((PumpSpeed_t)MANUAL_M3_DUTY);
      #endif

  #elif CONTROL_MODE == CONTROL_SOIL_ONLY

      /*
       * Soil-only mode:
       * M1/M2 are manual.
       * M3 is controlled by soil moisture.
       */
      Set_Converter_Duty(MANUAL_M1_DUTY);
      Run_Soil_Moisture_Control();
      Print_Panel_Sensors();

  #elif CONTROL_MODE == CONTROL_MPPT_AND_SOIL

      /*
       * Combined final mode:
       * MPPT controls M1/M2.
       * Soil moisture controls M3.
       */
      Run_MPPT();
      Run_Soil_Moisture_Control();
      Print_Panel_Sensors();

  #else

      /*
       * Fallback safety mode.
       */
      Set_Converter_Duty(0);
      Set_Pump_Speed(PUMP_OFF);

  #endif

    /* USER CODE END 3 */
  }
    /* USER CODE END WHILE */
}

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
/* USER CODE BEGIN 4 */
void find_calibration_values(void)
{
    const uint32_t calibration_time_ms = 30000;  // 30 seconds
    uint32_t start_time = HAL_GetTick();

    char msg[160];

    snprintf(msg, sizeof(msg),
             "\r\nStarting calibration. Ensure NO voltage and NO current input.\r\n");
    HAL_UART_Transmit(&huart2, (uint8_t*)msg, strlen(msg), 100);

    /* Reset accumulators */
    __disable_irq();
    v_sum = 0;
    i_sum = 0;
    sample_count = 0;
    __enable_irq();

    /* Wait while ADC DMA callbacks collect samples */
    while ((HAL_GetTick() - start_time) < calibration_time_ms)
    {
        HAL_Delay(1000);

        snprintf(msg, sizeof(msg),
                 "Calibrating... %lu / 30 seconds\r\n",
                 (unsigned long)((HAL_GetTick() - start_time) / 1000));
        HAL_UART_Transmit(&huart2, (uint8_t*)msg, strlen(msg), 100);
    }

    // STOP THE TIMER AFTER CALIBRATION IF NEEDED
    // HAL_TIM_OC_Stop(&htim1, TIM_CHANNEL_1);

    /* Copy final accumulated values safely */
    __disable_irq();
    uint64_t v_sum_copy = v_sum;
    uint64_t i_sum_copy = i_sum;
    uint32_t count_copy = sample_count;
    __enable_irq();

    if (count_copy == 0)
    {
        snprintf(msg, sizeof(msg),
                 "Calibration failed: no ADC samples collected.\r\n");
        HAL_UART_Transmit(&huart2, (uint8_t*)msg, strlen(msg), 100);
        return;
    }

    float v_raw_avg = (float)v_sum_copy / (float)count_copy;
    float i_raw_avg = (float)i_sum_copy / (float)count_copy;

    float voltage_offset = (v_raw_avg / ADC_MAX_COUNTS) * ADC_VREF;
    float current_zero_v = (i_raw_avg / ADC_MAX_COUNTS) * ADC_VREF;

    snprintf(msg, sizeof(msg),
             "\r\nCalibration complete\r\n");
    HAL_UART_Transmit(&huart2, (uint8_t*)msg, strlen(msg), 100);

    snprintf(msg, sizeof(msg),
             "Voltage raw avg: %.2f counts\r\n", v_raw_avg);
    HAL_UART_Transmit(&huart2, (uint8_t*)msg, strlen(msg), 100);

    snprintf(msg, sizeof(msg),
             "Current raw avg: %.2f counts\r\n", i_raw_avg);
    HAL_UART_Transmit(&huart2, (uint8_t*)msg, strlen(msg), 100);

    snprintf(msg, sizeof(msg),
             "Use this VOLTAGE_OFFSET: %.4f\r\n", voltage_offset);
    HAL_UART_Transmit(&huart2, (uint8_t*)msg, strlen(msg), 100);

    snprintf(msg, sizeof(msg),
             "Use this ACS_ZERO_V: %.4f\r\n\r\n", current_zero_v);
    HAL_UART_Transmit(&huart2, (uint8_t*)msg, strlen(msg), 100);
}

void find_moisture_calibration(void)
{
    char msg[200];

    snprintf(msg, sizeof(msg),
             "\r\n=== Moisture Sensor Calibration ===\r\n"
             "Step 1: Hold sensor in DRY AIR for 10 seconds (starts in 3s)...\r\n");
    HAL_UART_Transmit(&huart2, (uint8_t*)msg, strlen(msg), 100);
    HAL_Delay(3000);

    uint32_t air_sum = 0, air_n = 0;
    uint32_t start = HAL_GetTick();
    while ((HAL_GetTick() - start) < 10000) {
        air_sum += Read_Moisture();
        air_n++;
        HAL_Delay(50);
    }
    uint16_t air_avg = (uint16_t)(air_sum / air_n);

    snprintf(msg, sizeof(msg),
             "AIR average: %u counts\r\n\r\n"
             "Step 2: Submerge sensor in WATER. Starting in 10 seconds...\r\n",
             air_avg);
    HAL_UART_Transmit(&huart2, (uint8_t*)msg, strlen(msg), 100);
    HAL_Delay(10000);

    snprintf(msg, sizeof(msg),
             "Recording WATER values for 10 seconds...\r\n");
    HAL_UART_Transmit(&huart2, (uint8_t*)msg, strlen(msg), 100);

    uint32_t water_sum = 0, water_n = 0;
    start = HAL_GetTick();
    while ((HAL_GetTick() - start) < 10000) {
        water_sum += Read_Moisture();
        water_n++;
        HAL_Delay(50);
    }
    uint16_t water_avg = (uint16_t)(water_sum / water_n);

    snprintf(msg, sizeof(msg),
             "WATER average: %u counts\r\n\r\n"
             "=== Calibration Results ===\r\n"
             "MOISTURE_AIR_VALUE = %u\r\n"
             "MOISTURE_WATER_VALUE = %u\r\n"
             "Update these defines and rebuild.\r\n\r\n",
             water_avg, air_avg, water_avg);
    HAL_UART_Transmit(&huart2, (uint8_t*)msg, strlen(msg), 100);
}
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

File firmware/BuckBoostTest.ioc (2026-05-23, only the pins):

Mcu.UserName=STM32F446RETx
PA0-WKUP.Signal=ADCx_IN0
PA1.Signal=ADCx_IN1
PA10.Signal=S_TIM1_CH3
PA13.GPIO_Label=TMS
PA13.Signal=SYS_JTMS-SWDIO
PA14.GPIO_Label=TCK
PA14.Signal=SYS_JTCK-SWCLK
PA2.GPIO_Label=USART_TX
PA2.Signal=USART2_TX
PA3.GPIO_Label=USART_RX
PA3.Signal=USART2_RX
PA5.GPIO_Label=LD2 [Green Led]
PA5.Signal=GPIO_Output
PA8.Signal=S_TIM1_CH1
PA9.Signal=S_TIM1_CH2
PB3.GPIO_Label=SWO
PB3.Signal=SYS_JTDO-SWO
PC1.Signal=ADCx_IN11
PC13.GPIO_Label=B1 [Blue PushButton]
PC13.Signal=GPXTI13
PC14-OSC32_IN.Signal=RCC_OSC32_IN
PC15-OSC32_OUT.Signal=RCC_OSC32_OUT
PH0-OSC_IN.Signal=RCC_OSC_IN
PH1-OSC_OUT.Signal=RCC_OSC_OUT

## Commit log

2026-05-23 Reorganise into firmware/ and hardware/ subfolders
    [Buck_Converter.kicad_sch, Current_Sensor.kicad_sch, GateDriver.kicad_sch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]
2026-05-23 Revise README for solar-powered irrigation project
    Updated the README to reflect the solar-powered buck-boost converter project details, including an overview, repository structure, hardware specifications, firmware features, and instructions for bui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

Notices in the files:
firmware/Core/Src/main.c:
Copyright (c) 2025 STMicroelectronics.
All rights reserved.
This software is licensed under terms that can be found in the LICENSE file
